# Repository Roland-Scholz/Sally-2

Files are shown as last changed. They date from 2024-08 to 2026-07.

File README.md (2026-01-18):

# Sally-2

An ATR8000 (https://www.atarimagazines.com/v3n4/ATR8000.php, http://atariki.krap.pl/index.php/ATR_8000) clone formerly made by SWP
and the Sally 1 by RSD (Rainer Storz Datentechnik)

Inspired by the repair of a Sally 1, which had been found in the attic, the
Atari-Bit-Byter-User-Club (www.abbuc.de) encouraged Marc and me to reproduce this lovely machine in a more compact way, 
though keeping a sort of retro-style.

We used 3 16V8 GALs in order to reduce chip count and replaced the WD1797 floppy-disc-controller by the more compact
WD1772 variant. Caveat: This chip is not designed for HD (500kbit/s) speed used by 3 1/2" and 8"-drives, although most 
can be overclocked to that speed. Only use WD1772PH-02-02 version and at your own risk.
If you can get hold on an AJAX chip used in e.g. ATARI STE, use this one as it is rated for HD and even ED speed (16/32 Mhz).

Build your own device: All required files, components and documentations can be found in the release drawer 
https://github.com/Roland-Scholz/Sally-2/tree/main/release

You also could become an ABBUC member and buy a DIY kit at https://www.abbuc.de
Join the illustrous community and take part in conventions and discussions.

After some testing and debugging, the vRetro VR177x FDC replacement can now be recommended for use with this interface.
See https://www.vretrodesign.com/products/vr177x-wd1770-wd172-vl1772-replacement

# FAQ
[click here for FAQ](faq.md)

# ToDo:
[click here for ToDo](todo.md)

# Key features:

- Operates either as standalone CP/M system or versatile ATARI 8-bit interface (up to 4 floppies, Centronics, RS232)
- Z80-CPU at 4Mhz
- 128k static RAM (64k usable)
- 8k EPROM, use any 8 / 16 / 32 / 64k device (burn sally2.hex at $8000)
- WD1772 FDC (or AJAX FDC or VR177x)
- Z80-CTC timer/counter 

Additionally we have added:

- 60.000 baud high speed SIO (Pokey divisor 8, drive responds to the "Get Speed Byte" command '?')
- Track buffer
- HD-support for 3 1/2" disks (ca. 1MB). (Format is same as 8", 2 sides, 77 tracks, 26 sectors/track, 256 bytes per sector)

# Final product ready as of October 2025

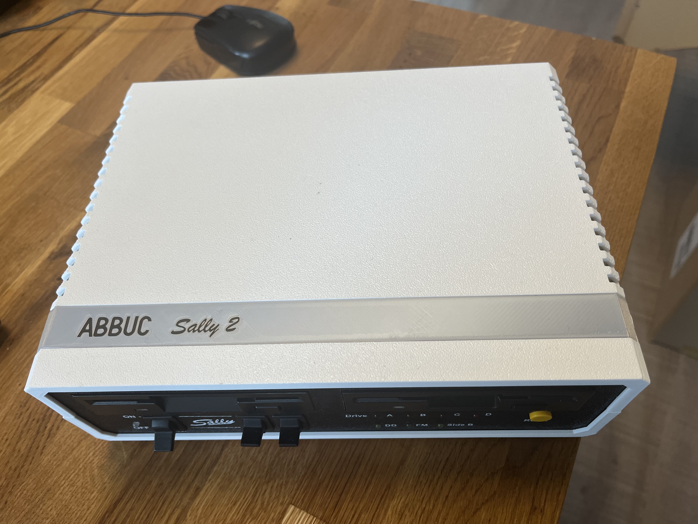
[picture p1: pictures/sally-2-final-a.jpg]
Sally-2-final-a

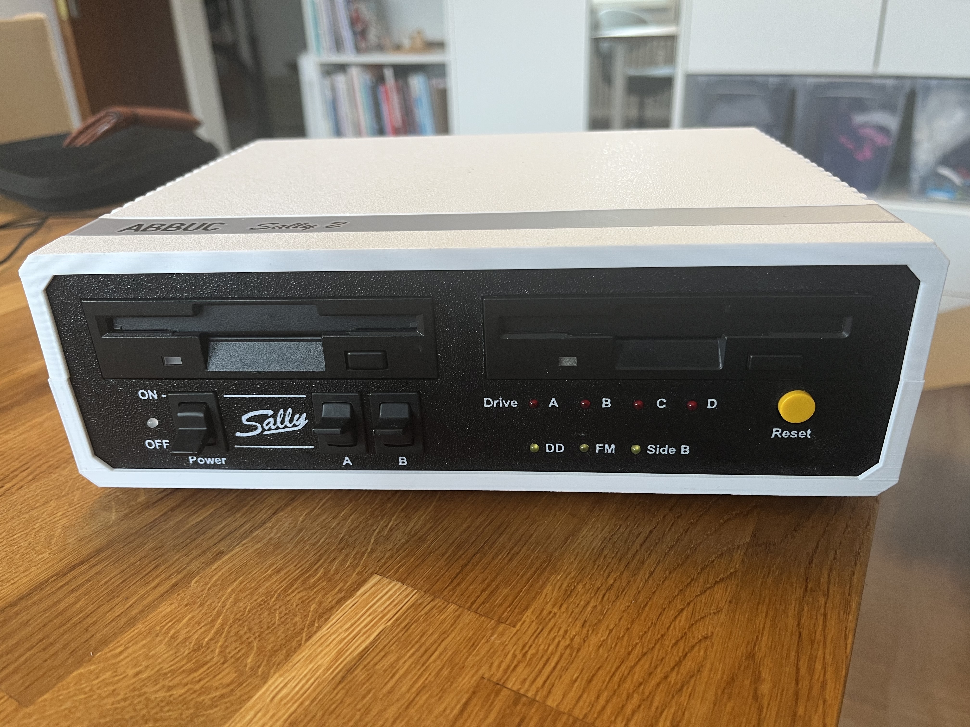
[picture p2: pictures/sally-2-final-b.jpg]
Sally-2-final-b


# further progress as of April 2025:

- Marc has completed a new manually routed PCB and 3 supporting PCBs for swicthes and connectors
- ATARI can read/write 3 1/2 HD disks formtted like 8"-disks (26sec x 77 trks x 2 sides = ca. 1MB)
  The challange was to allow for HD even for 300 rpm drives, instead of 360rom used by 8" and 5 1/4" drives.
- A full blown FAT-12 DOS for the ATARI is close to be finished, some more testing and minor additional features required/appreciated
- ABBUC now owns a Bumbu X1-carbon 3D printer, which has immediately been used to dress Sally-2 appropirately.

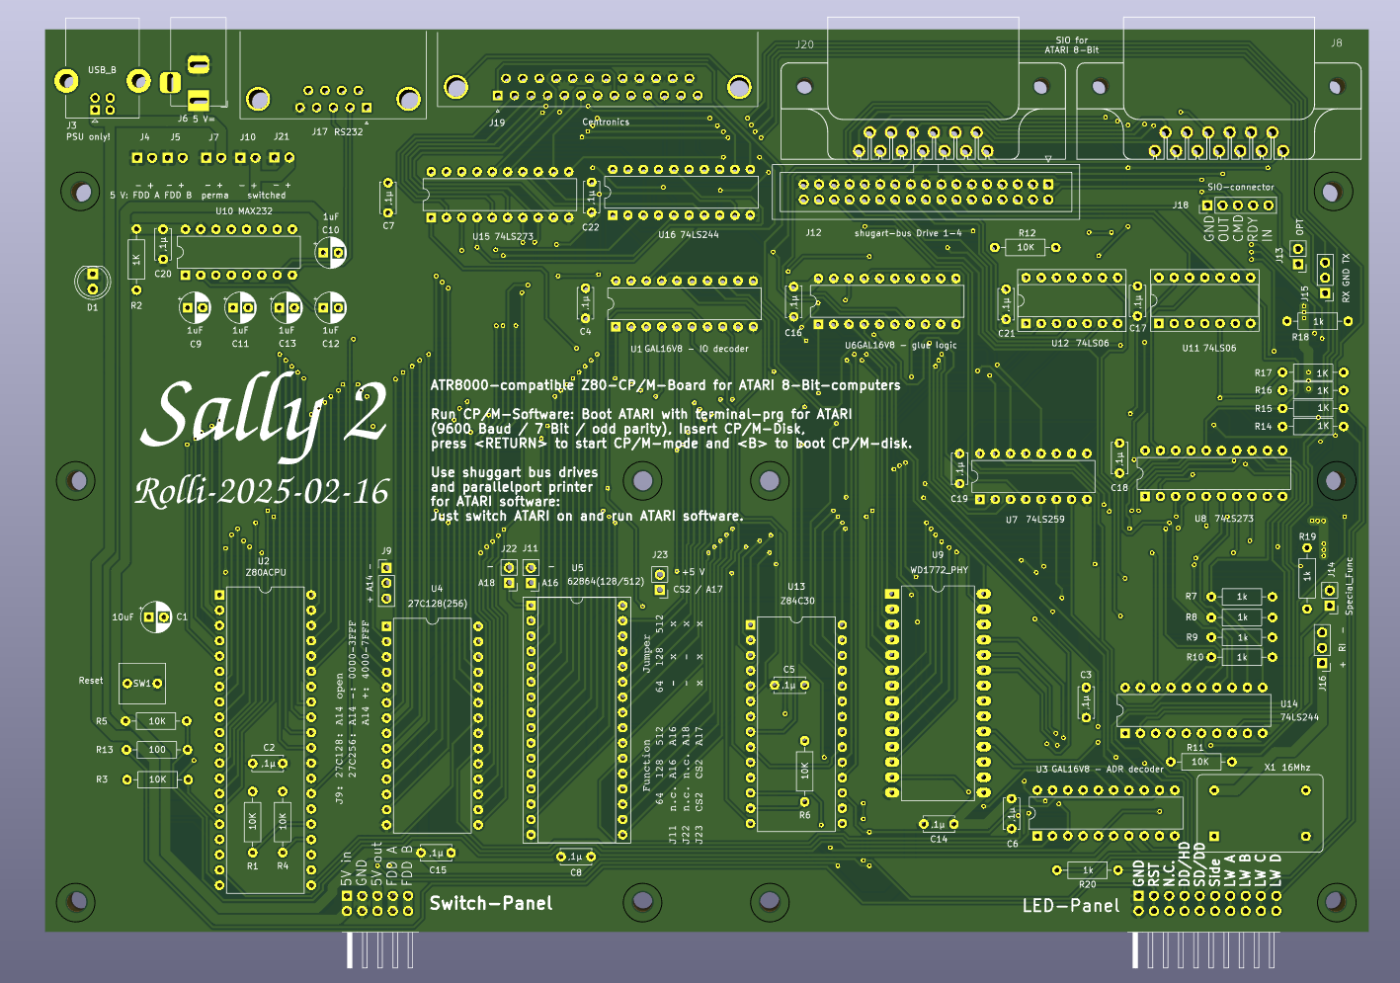
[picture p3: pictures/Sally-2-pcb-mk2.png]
Sally-2-pcb-mk2

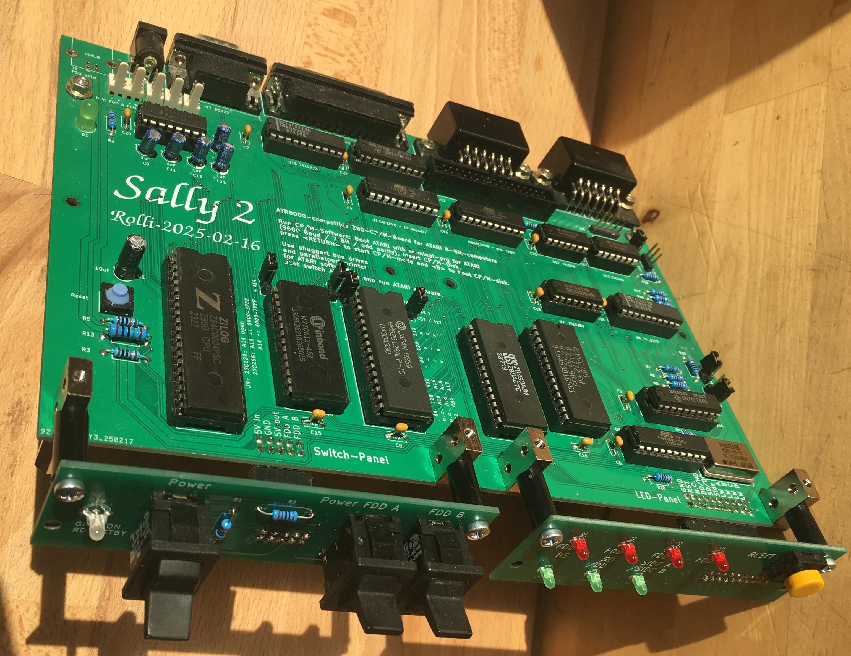
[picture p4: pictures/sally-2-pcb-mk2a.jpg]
Sally-2-pcb-mk2a

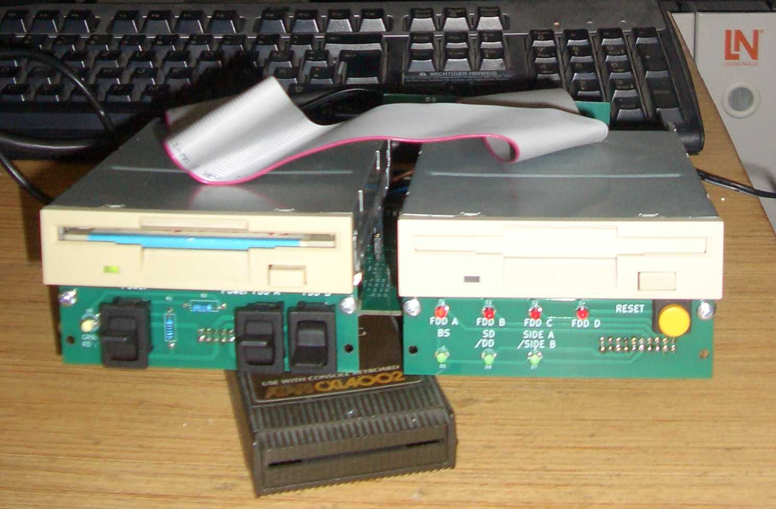
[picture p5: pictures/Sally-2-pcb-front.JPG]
Sally-2-pcb-front

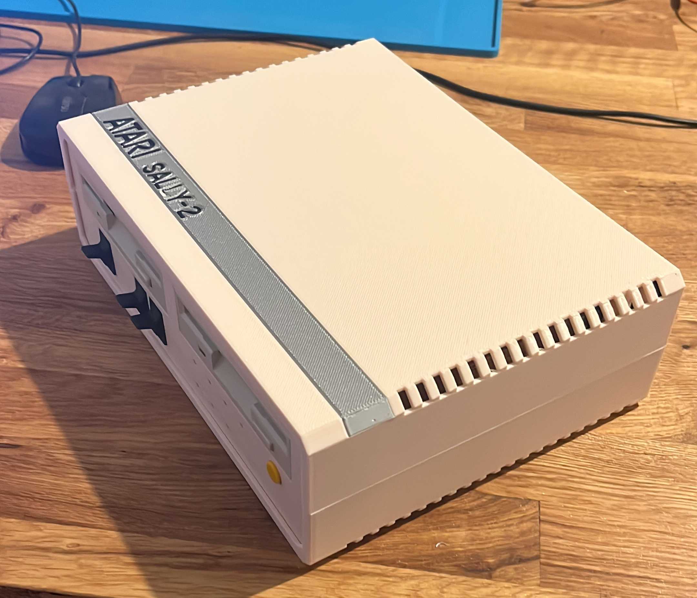
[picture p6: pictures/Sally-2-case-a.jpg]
Sally-2-case-a

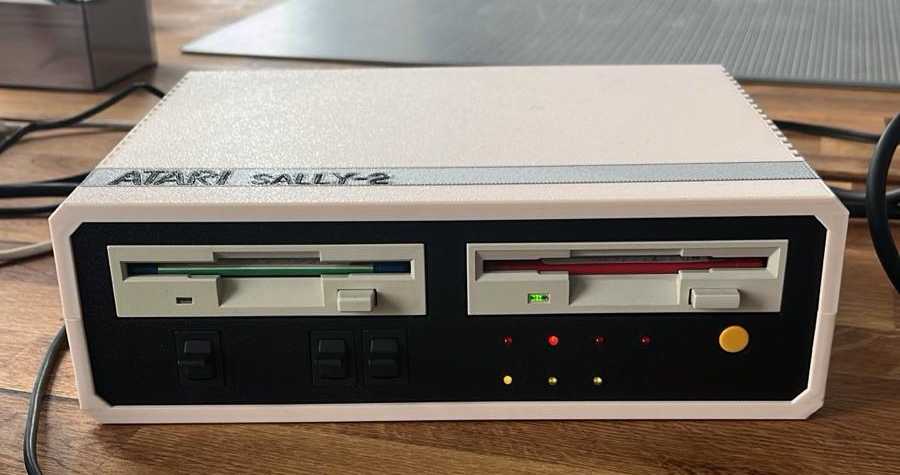
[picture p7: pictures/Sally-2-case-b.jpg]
Sally-2-case-b

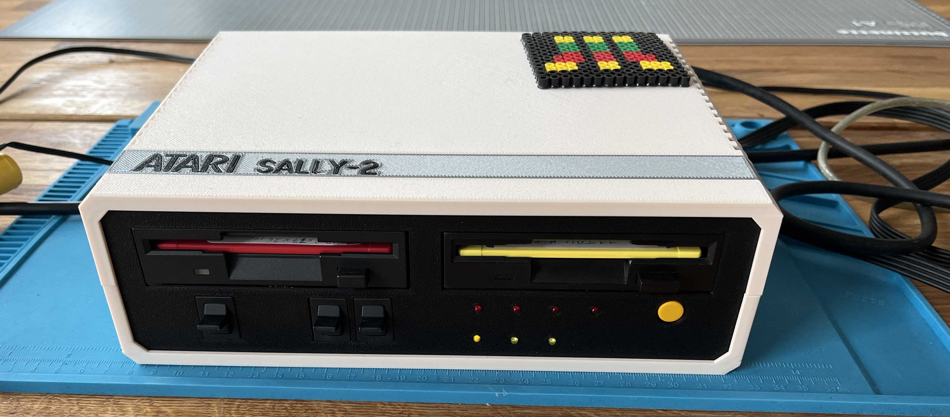
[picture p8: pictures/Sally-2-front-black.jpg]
Sally-2-case-front-black

First try, all-in-one print, label and case
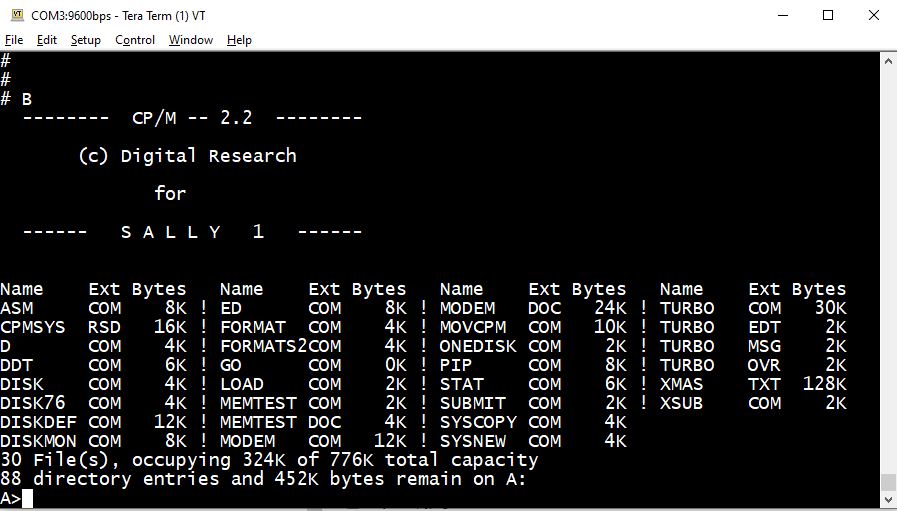
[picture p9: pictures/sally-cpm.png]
sally-cpm

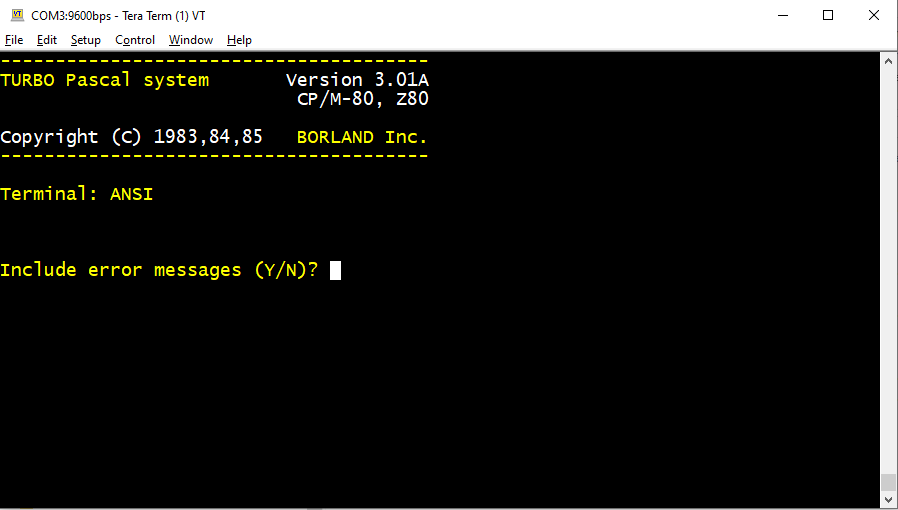
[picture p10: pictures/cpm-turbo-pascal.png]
cpm-turbo-pascal


# first attempts
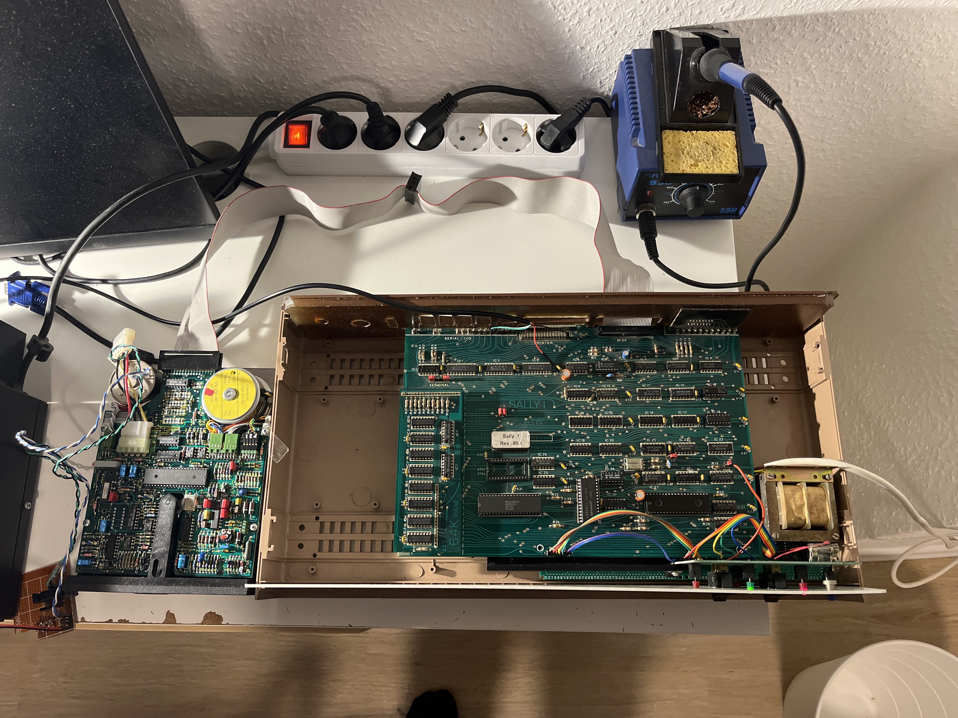
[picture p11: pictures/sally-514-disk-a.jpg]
Sally-514-disk-a

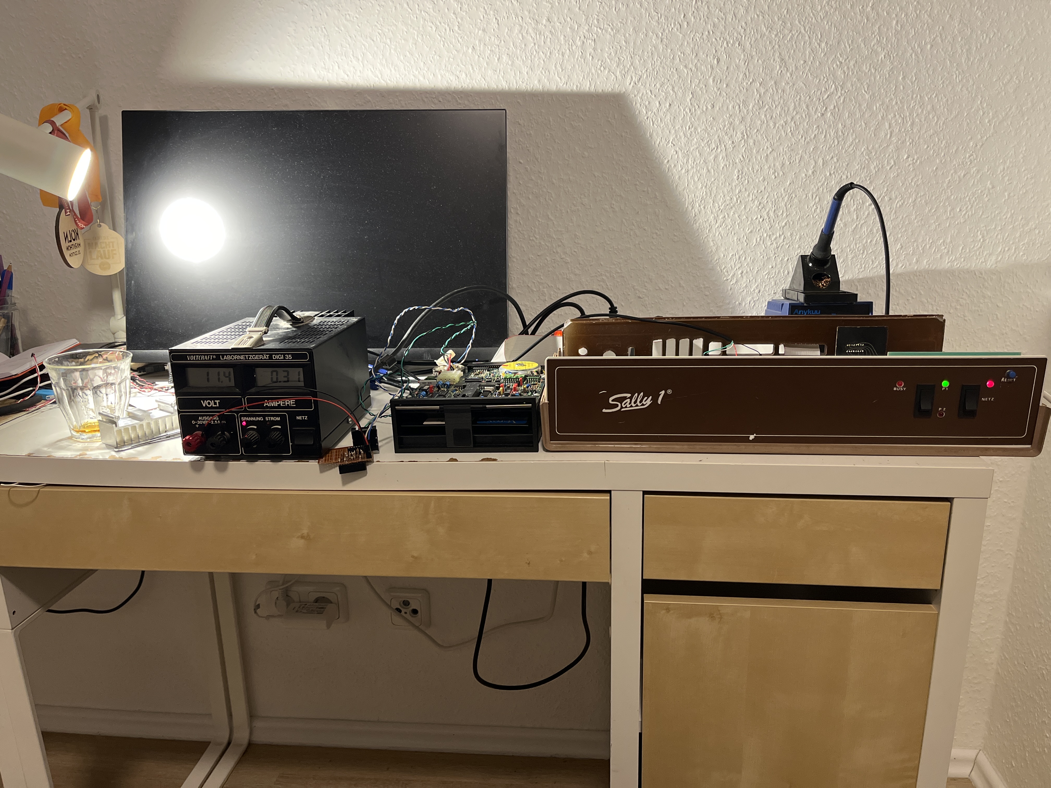
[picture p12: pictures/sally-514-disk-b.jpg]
Sally-514-disk-b

Original Sally 1 repaired (5 ICs were out of order) and tested with a 40Trk single sides drive.

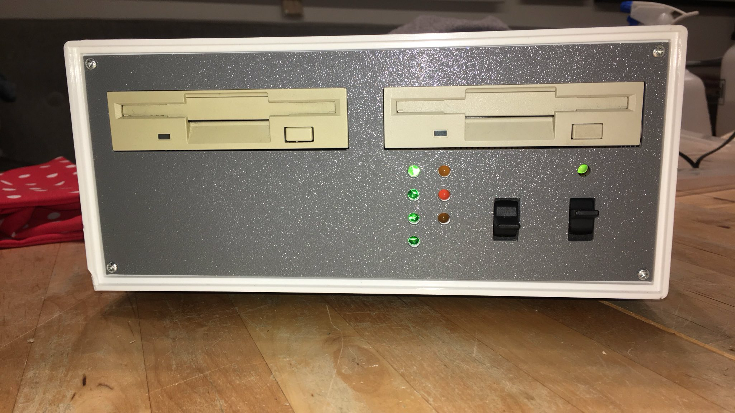
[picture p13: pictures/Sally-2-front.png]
Sally-2-front

Sally-2-back
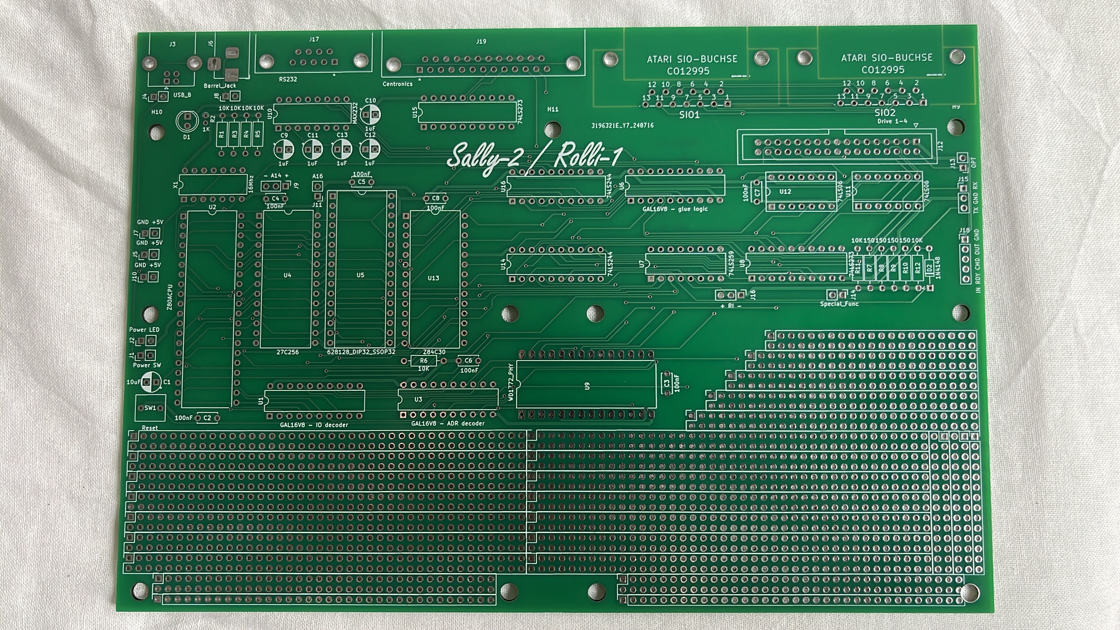
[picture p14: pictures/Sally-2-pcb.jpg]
Sally-2-pcb

First version of Sally 2 PCB and a case

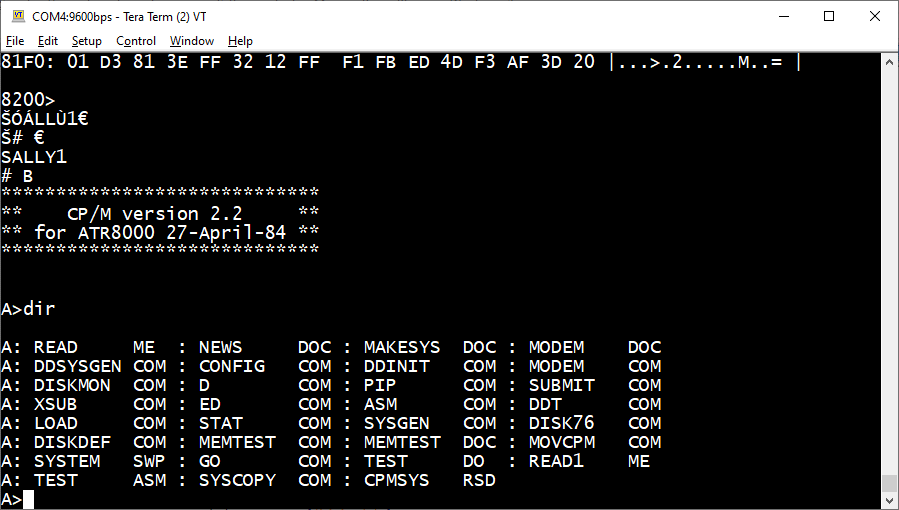
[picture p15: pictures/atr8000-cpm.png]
Atr8000-cpm

ATR8000 CP/M running on Sally 1 (todo: Add picture of the Sally CP/M version, which is apart from the messages identical to the ATR8000)

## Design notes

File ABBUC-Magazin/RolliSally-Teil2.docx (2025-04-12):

Rolli und Sally – Liebe auf den zweiten Chip

Teil II

Liebe Bit-Byter,

es ist schon wieder einige Zeit her, dass ich über die Reparatur der Sally, dem Fund aus Wolfgangs Keller, an dieser Stelle berichtet habe. Diesmal möchte ich ein wenig über die Fähigkeiten der Sally schreiben und was Marc (sleepπ) und ich (chaos) in der vergangenen Zeit so getrieben haben.

Also was ist die Sally eigentlich genau?

Versuchen wir einen Vergleich: Die Sally ist im Grunde ein von der Firma RSD (Rainer Storz Datentechnik, Duisburg) ausgeführter Nachbau des Interfaces ATR8000 der Firma SWP aus den USA. Hinzugefügt wurden nur kleinere Änderungen, die später noch beschrieben werden. Wir wissen zur Zeit nicht, ob das Gerät je in Serie Verkauft wurde, denn die zwei einzigen uns bekannten Stücke sind zwar funktionstüchtig, hätten aber wahrscheinlich aus sicherheitstechnischen Gründen nicht auf den deutschen Markt gebracht werden können bzw. dürfen.

Nun zur Frage, wenn die Sally im Prinzip ein ATR8000 ist, was kann bzw. ist denn dann ein ATR8000?

Die Hardware:

Prinzipiell besteht ein ATR8000 aus einer Z80-CPU, 64KB-RAM, 8-32KB ROM (abschaltbar), einem Z80-CTC (Timer/Counter) und einem WD 1797 Floppy-Disk-Controller, der so ziemlich alle Formate gängigen schreiben/lesen kann. Auch kann er mit 250kbit/sec oder mit 500kbit/sec arbeiten, sodass sowohl DD- als auch HD-Disketten verarbeitet werden können. Somit sind alle Diskettengrößen von 8-Zoll bis 3 ½ Zoll, Aufzeichnungsdichten und -formate (FM/MFM) einsetzbar. Lediglich das GCR-Verfahren, das Commodore und Apple verwendeten, kann nicht benutzt werden. Bis zu vier Diskettenlaufwerke können über den Shugart-Bus angeschlossen werden. Das sind die (früher) handelsüblichen Laufwerke, die es in vielen Variationen gibt. IBM hat für den PC den Shugart-Standard (leider) etwas verändert, aber mit einem passenden (u.U. selbst-konfektionierten) Kabel kann man auch PC-Laufwerke verwenden. Ohne viel Aufwand dann jedoch nur zwei, weil die Select-Leitungen der Shugart-Laufwerke 3 und 4 als Motor-ON Signale der PC- Laufwerke 1 und 2 verwendet worden sind.

Die Betriebsmodi:

Ein ATR8000 hat zwei Betriebsmodi: Einmal kann es als ATARI-Interface dienen und in dieser Betriebsart dem ATARI bis zu vier Diskettenlaufwerke, einen seriellen RS232 Port und eine Centronics-(Drucker)-Port zur Verfügung stellen. Zum anderen kann es sozusagen „stand-alone“ als Computer-System mit dem Betriebssystem CP/M betrieben werden. An dem SIO-Port des ATR8000 wird dann ein ADM-3A Terminal benötigt. Es gibt dazu sogar zwei passende Terminal-Emulationen für den ATARI, eine, die im 40-Zeichen Modus arbeitet und eine, die einen in Software emulierten 80-Zeichen-Modus bietet. Ein CP/M 2.2-Betriebssystem mit einigen Werkzeugen liegt dem System bei.

ATARI-Modus:

Im ATARI-Interface Modus werden bei DD-Disketten immer 18 Sektoren pro Track geschrieben. Das bedeutet aber auch, dass das sogenannte Enhanced-Density mit 26 Sektoren, nicht verarbeitet werden kann. Durch die Konfiguration des PERCOM-Blocks muss der Nutzer festlegen, welches Aufzeichnungsformat verwendet werden soll, also wie viele Tracks pro Seite und wie viele Seiten die Diskette haben soll. Das Aufzeichnungsformat kann entweder FM bzw. single-density oder MFM bzw. double-density sein. Da die meisten Diskettenlaufwerke 80 Tracks unterstützen, ist ein typisches Format, das mit 250kbit/sec geschrieben wird, wäre z.B.:

256 Bytes * 18 Sektoren * 80 Tracks * 2 Seiten = 720KB

Der Floppy-Disk-Controller aber auch mit 500kbit/sec, also mit HD (high-density) lesen und schreiben. 8-Zoll Laufwerke und die vom PC bekannten HD-Laufwerke können diese Dichte verwenden. Die 8-Zoll-Laufwerke sind mit 77 Tracks spezifiziert, daher formatiert ein ATR8000 dann eine Diskette mit

256 Bytes * 26 Sektoren * 77 Tracks * 2 Seiten = 1001KB

Wieder über den PERCOM-Block kann man diese Werte einstellen, insbesondere wird an der Eingabe von 77 Tracks erkannt, dass die Schreibdichte doppelt so hoch sein soll. Auf einer modernen 3 ½ Zoll Diskette (früher waren sie modern im Vergleich zu 8-Zoll Laufwerken) könnte man noch drei Tracks und wegen der geringeren Drehzahl von 300upm gegenüber den 360upm eines 8-Zoll Laufwerks auch mehr Sektoren pro Track unterbringen. Die Anpassung der Firmware und die Unterscheidung der Formate wären aber recht kompliziert. Eine gängige HD-Diskette speichert ja 1440KB, das wären schon noch ein paar KB mehr.

Weiterhin bietet das ATR8000 auch eine RS232 Schnittstelle, die bis 19200 betrieben werden kann. Im praktischen Betrieb unter CP/M mit einer XMODEM Terminal-Software konnte ich es nur bis 9600 Baud stabil verwenden. Auch im ATARI-Modus mit einem Treiber für Bobterm oder ICE-Term war ein XMODEM-Transfer nur bis 9600 Baud stabil.Auch wenn die Hardware eingeschränkt auch Datenfluss-Kontrollsignale bereitstellt (RTS/CT bzw. DSR/DTR), so wurden diese, soweit ich das erkennen konnte, von keinem Treiber verwendet.

Die Centronics-Schnittstelle funktioniert gut und das interne RAM wird als Druckerpuffer verwendet. Besondere Auffälligkeiten konnten Marc und ich bisher nicht feststellen.

CP/M-Modus:

CP/M war eines der ersten Betriebssysteme für Kleincomputer, das sämtliche Ein-/Ausgaben über einen Satz von einfachen BIOS-Routinen ausführt. Somit müssen für ein neues Computersystem nur diese BIOS-Routinen angepasst werden und schon läuft ein CP/M. Ein Nachteil war allerdings dass das BIOS nur zeichenbasiert arbeitet und im Grunde immer für eine Art Terminal vorgesehen war und damit spezifische Fähigkeiten hinsichtlich Grafik oder Sound nicht standardisiert verwendet werden konnte. Das sieht man z.B. daran, dass das bekannte Turbo-Pascal von Borland bestimmt 40 Treiber für verschiedenen Systeme mitlieferte. Aber wie gehabt, die Ein-Ausgabe auf Geräte wie Terminal, Drucker und Diskettenlaufwerke sind abstrahiert und schnell an neue Rechner anpassbar.

Der ATR8000 wie die Sally bringen ein jeweils ein (identisches) CP/M 2.2 mit, dessen BIOS dann auf die Hardware des ATR8000 zugreift. Für die Sally wurden die Meldungstexte eingedeutscht, die Funktion und Umfang der Tools hat sich nicht geändert.

Es gibt Programme zur Formatierung von Disketten, ein Terminal-Programm und weitere Tools um bestimmte Diskettenformate zu setzten. Auch kann man sein CP/M-System klonen oder neu konfigurieren. Denn die Geometrie der angeschlossenen Laufwerke müssen dem CP/M in bestimmten Kontrollblöcken in den Boot-Sektoren mitgeteilt werden. Das CP/M wird auf die ersten (dafür reservierten) Tracks einer Diskette geschrieben und bei einem Neustart von diesen Tracks eingelesen.

Die serielle Kommunikation mit dem Terminal muss auf 9600 Baud, 7 Bit und odd Parity eingestellt werden und als Terminal-Steuerzeichen wird das Befehlssatz der ADM-3A Terminals verwendet. Ein recht einfaches Terminal, das auch nur Großbuchstaben verwendet.

Im Bild ist dargestellt, wie gerade Borland Turbo Pascal 3.02 gestartet ist und über ein VT100-Terminal bedient wird. Im Grunde sollte auch jede anderen CP/M-Software mit dem System laufen.

Sally:

Die Sally-Firmware ist bis auf die Texte Byte für Byte identisch mit der ATR8000-Firmware, wir haben die ROMs verglichen. Dennoch gibt es folgende Änderungen an der Hardware:

Sie hat eine Busy-Lampe, die immer dann leuchtet, wenn entweder auf ein Diskettenlaufwerk oder auf die serielle Schnittstelle zugegriffen wird.

Sie hat 4 SIO-Ports, man kann also mehrere ATARIs an die Sally anschließen. Jedoch muss man ohne den Prioritätsencoder (s.u.) dringend darauf achten, dass immer nur ein ATARI auf der SIO-Leitung aktiv ist. Aus meiner Sicht ein recht fragwürdiges Feature.

Weiterhin gibt es eine kleine Erweiterung, die den SIO-Ports Prioritätsencoder hinzufügt. Wenn als gerade ein ATARI Daten austauscht, sind die anderen ATARI von der Kommunikation hardwaremäßig abgetrennt. Das verhindert ein wenig Datensalat auf der SIO-Leitung, ergibt aber m.E. immer noch kein vollwertiges/verlässliches Multi-Computer Netzwerk.

Sally-2:

Carsten (Cas) hatte angeregt, ob Marc und ich nicht einen leicht modernisierten Nachbau der Sally konstruieren und der Allgemeinheit zugänglich machen könnten. Unsre Ehrgeiz war schnell geweckt und schon im Juni 2024 hatten wir die erste Platine auf dem Schreibtisch liegen. Nachzulesen ist das alles en detail im Basecamp der AReWe. Aber hier zuerst einmal die Grundgedanken:

- Irgendwie sollte es ein wenig Retro sein, da ja Disketten selbst mit dem Atari kaum noch verwendet werden und fast jeder ein SD-Leser oder ein Fujinet am Start hat. Man könnte auch alles in einem Microcontroller emulieren, aber das ist nicht unser Geist.
- Funktionsumfang gleich dem des ATR8000, da die Sally-Erweiterungen marginal bis nutzlos sind.
- Floppy-Controller: Umstieg auf den WD1772-PH-02-02, denn der WD1797 ist wirklich gar nicht mehr zu bekommen und die PLL-Schaltung funktioniert extern mit einem PROM, das mit 25V programmiert werden muss und auch so gut wie nicht mehr erhältlich ist. Der WD1772 hat den PLL mit eingebaut. Da er im ATARI ST, XF551 und andere Floppys eingebaut war, bekommt man ihn hier und da noch. Allerdings ist er eigentlich nur für DD (also 250kbit/sec) und nicht für HD spezifiziert. Jedoch lassen sich die meisten Chips der Version WD1772-PH-02-02 ohne Probleme übertakten und kommen auch mit HD (500kbit/sec) zurecht. Wem das zu kriminell ist, der nutzt eben nur SD/DD Disketten.
- Vereinfachung und Zusammenfassung der vielen 74LSxx-Logik-Bausteine in drei GAL16V8
- Dynamisches RAM wird durch statisches RAM ersetzt.
- Erweiterung der Firmware um:
  - 60.000 baud high speed SIO (Pokey divisor 8)
  - Track-Buffer
  - HD-Support für 3 1/2" disks (ca. 1MB). (Format wie für 8", 2 Seiten, 77 Tracks, 26 Sektoren/Track, 256 Bytes pro Sektor)
  - MS-DOS (FAT12) Format lesen/schreiben per neuem ATARI-DOS

Wie bei jedem Prototyp waren natürlich (kleine) Flüchtigkeitsfehler auf der Platine und leider auch ein Größerer, weil nämlich der Daten- und Adressbus zwischen CPU- und IO-Bereich durch eine Besonderheit von KiCad nicht verbunden waren. Auch hatte ich einen IO-Baustein falsch angeschlossen, weil ich den originalen Schaltplan nicht genau genug beachtet hatte. Aber nach ein wenig Schwingen des Lötkolbens hatten Marc und ich schnell die ersten Funktionstüchtigen Prototypen (Roland: Rolli, Marc: Molli) arbeitsbereit.

Das Umprogrammieren auf den nicht vollständig kompatiblen Floppy-Controller und Erweitern der Firmware war viel interessante Detektivarbeit und hat manchmal etwas Frust aber meistens viel Spaß gebracht. Die Sally-2 ist nun deutlich schneller als das Original und kann mit HD-Disketten im 3 ½-Format umgehen.

Aktuell schreibe ich noch an dem FAT12-DOS (90% fertig), würde mich aber freuen, wenn wir da Unterstützung bekommen könnten.

Nachdem ja jetzt die Prototyp-Platine funktionierte, hat Marc sich die Mühe gemacht und die Platine noch einmal von Hand komplett neu geroutet und alle Beschriftungen perfektioniert. Außerdem fanden wir das Metall-Gehäuse (ein blaues Standard-Teil aus China) nicht so passend zu unserem Atari, sodass Marc noch kleine Platinen für die Frontbedienung entwickelte und damit das Design in der Höhe deutlich reduzieren konnte. Jetzt warten wir auf einen neuen 3D-Drucker, den der ABBUC uns und allen Mitgliedern zur Verfügung stellt. Wenn er angekommen ist, werden wir versuchen uns in die Kunst des 3D-Drucks einzuarbeiten, mit dem Ziel ein ATARI-ähnliches Gehäuse (evtl. zwei Versionen, XL weiß-schwarz oder XE grau) für die Sally-2 zu erstellen. Anschließend planen wir die Sally-2 als Bausatz den ABBUC-Mitgliedern zum Selbstkostenpreis bestellbar zu machen.

Das war es erst einmal von meiner Seite. Ihr findet hier noch viele Links, falls Ihr Euch noch weiter in bestimmte Themen einlesen wollt. Fragen und Mitarbeit sind jederzeit sehr willkommen und wir halten Euch auf dem Laufenden wie es mit der Liebe auf den zweiten Chip weitergeht.

Euer Roland (chaos)

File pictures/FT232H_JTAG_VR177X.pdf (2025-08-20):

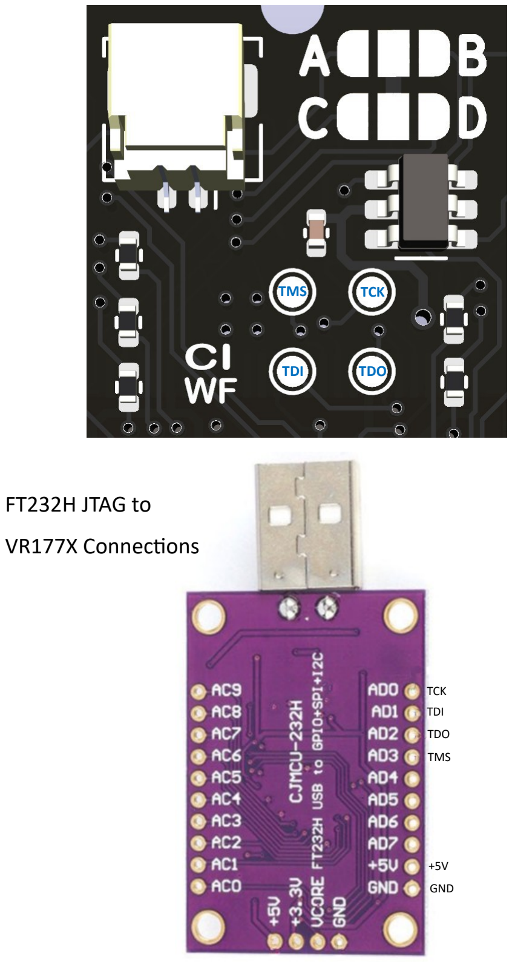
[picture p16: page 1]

TMS | TCK
TDI | TDO

TCK
TDI

TDO

TMS

+5V
GND

FT232H JTAG to

VR177X Connections

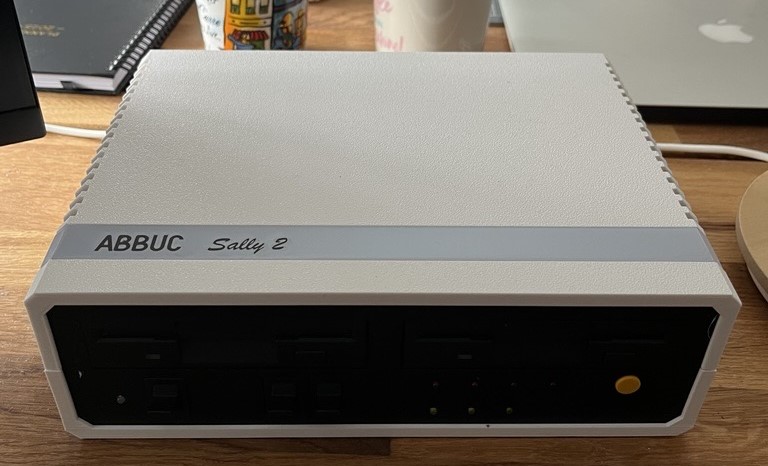
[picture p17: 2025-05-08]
pictures/sally-2-abbuc-a.jpg

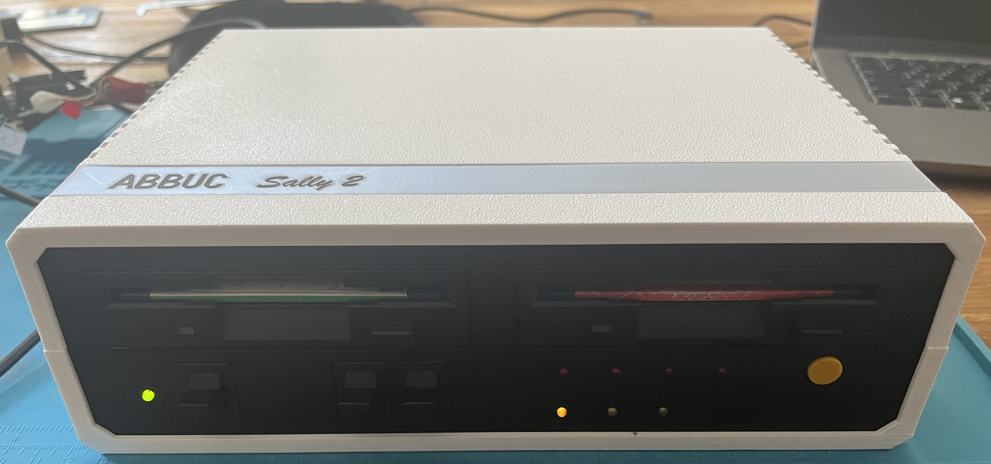
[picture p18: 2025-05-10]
pictures/Sally-2-front-black-a.jpeg

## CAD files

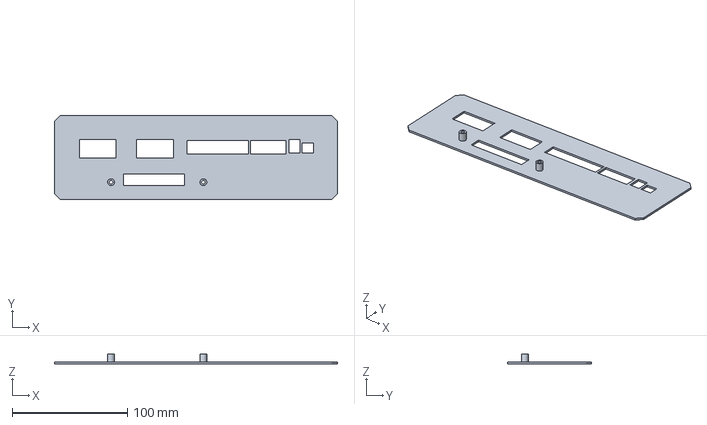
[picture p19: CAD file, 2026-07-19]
case/sally-2-back-text.3mf
245.2 x 73.2 x 8.60 mm

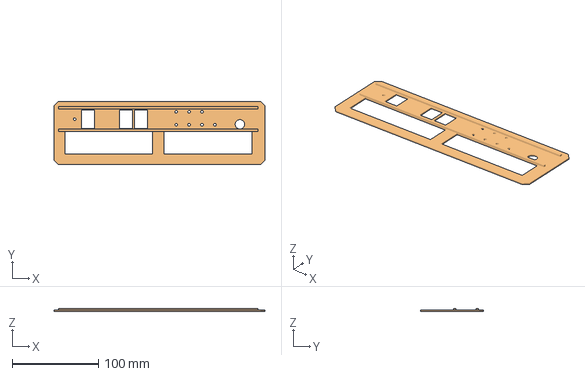
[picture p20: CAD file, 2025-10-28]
case/sally-2-front.3mf
245.2 x 73.2 x 3.60 mm
sally-2-front-text-logo.stl
sally-2-front.stl

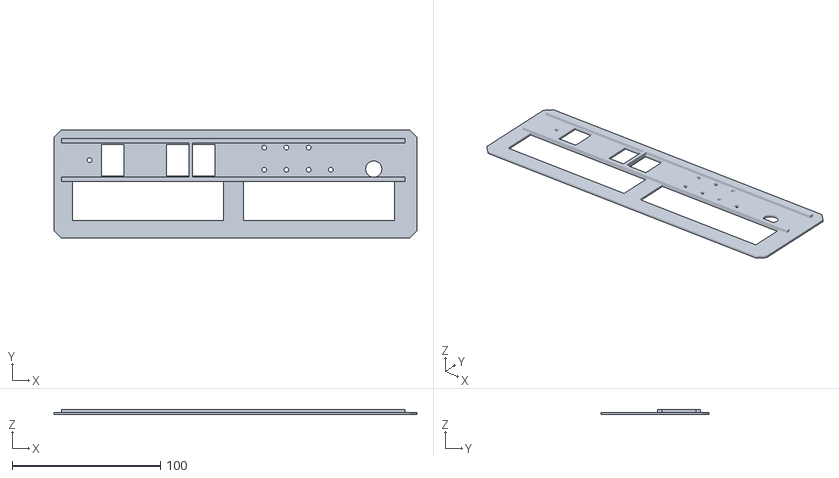
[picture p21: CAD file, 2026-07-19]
release/case/sally-2-front.stl
245.2 x 73.2 x 3.60

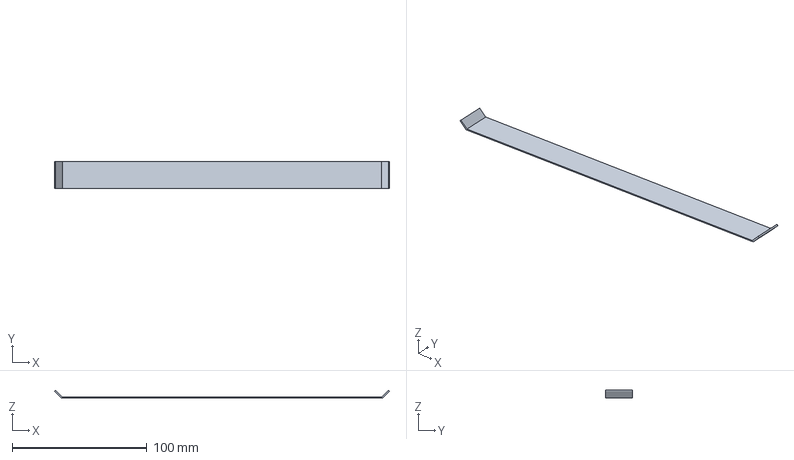
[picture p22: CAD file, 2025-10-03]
case/sally-2-top-1.3mf
249.0 x 20.0 x 5.80 mm

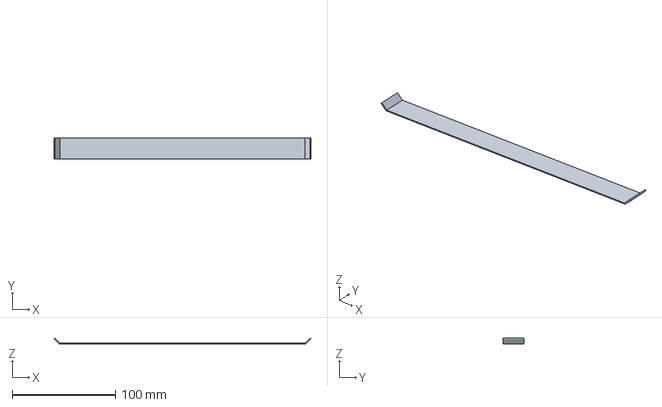
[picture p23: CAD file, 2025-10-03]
release/case/sally-2-top-2.3mf
249.0 x 20.0 x 5.80 mm

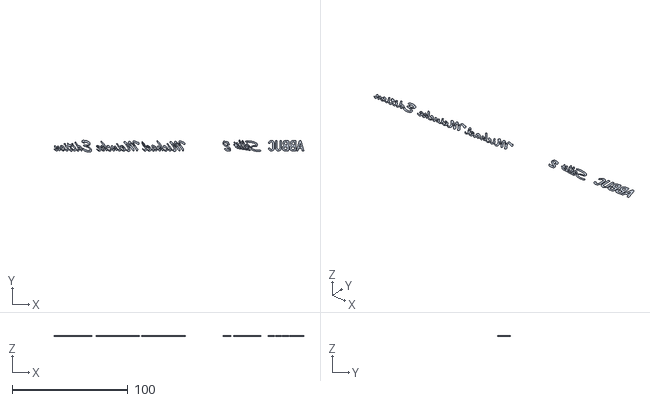
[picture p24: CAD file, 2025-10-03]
case/sally-2-top-2.stl
216.3 x 10.8 x 0.2

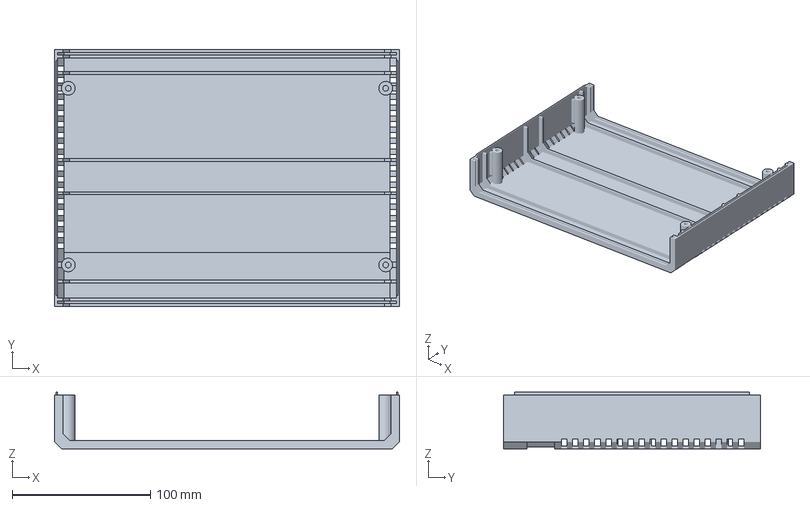
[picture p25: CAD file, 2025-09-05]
release/case/sally-2-top.3mf
250.0 x 186.0 x 41.0 mm

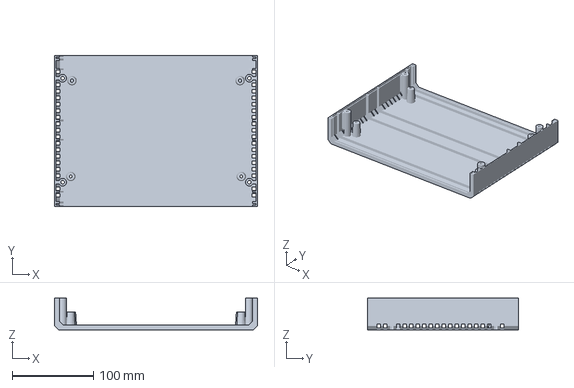
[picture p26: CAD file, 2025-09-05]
release/case/sally-2-bottom.3mf
250.0 x 186.0 x 39.0 mm

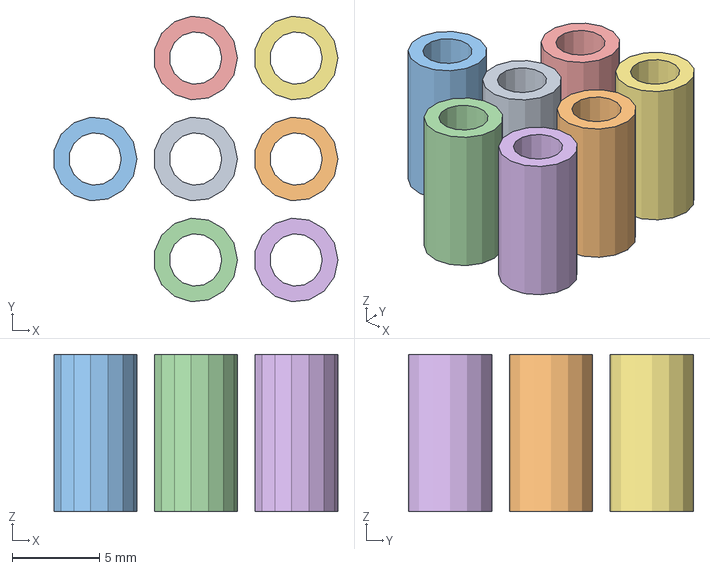
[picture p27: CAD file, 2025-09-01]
case/spacer-led.3mf
16.2 x 16.3 x 9.00 mm
spacer-led.stl x 7

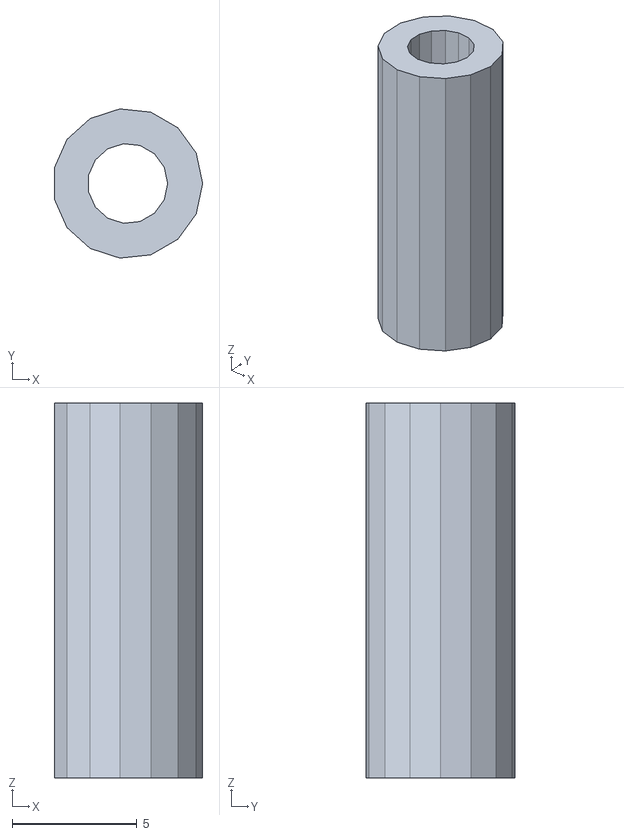
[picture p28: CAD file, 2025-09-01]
release/case/spacer-round-15.stl
5.93 x 5.97 x 15.0

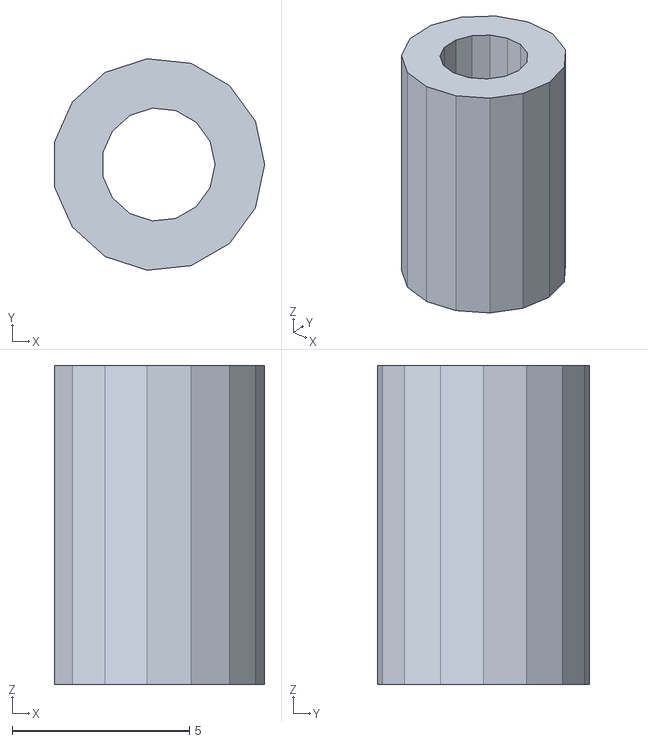
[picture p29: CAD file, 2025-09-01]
case/spacer-round-9.stl
5.93 x 5.97 x 9.00

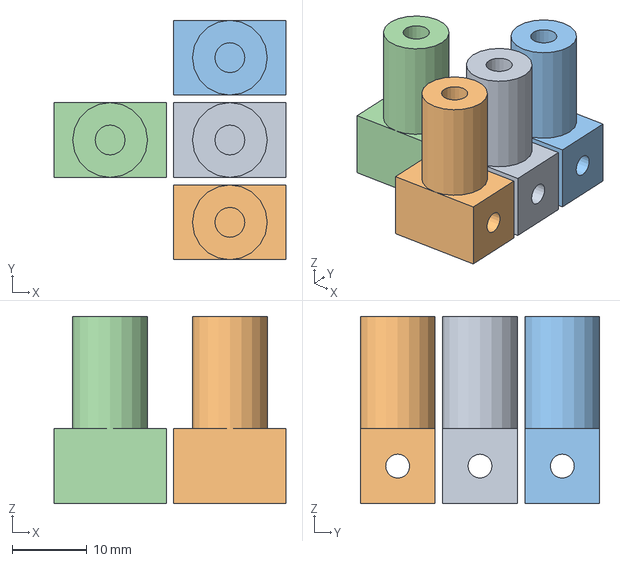
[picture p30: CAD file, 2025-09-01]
case/spacer.3mf
31.0 x 32.0 x 25.0 mm
spacer.stl x 4

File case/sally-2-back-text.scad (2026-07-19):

beschriftung();

module beschriftung() {
    
    translate([60, -46, 0])
    linear_extrude(0.4){
        rotate([180, 0, 0])
            text("1                SHUGART", 3, "Arial:style=Bold");
    }

    translate([33, -16, 0])
    linear_extrude(0.4){
        rotate([180, 0, 0])
            text("SIO                                      SIO                                 CENTRONICS                       RS232          Vin    FUNC", 3, "Arial:style=Bold");
    }

}

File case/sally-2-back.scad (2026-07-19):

$fn = 20;

thick = 2;
tf = 1.2;

xmax = 250;
ymax = 180+thick;
zmax = 39*2;

dev_x = 21.5;
dev_bot = 21;

edge=5;

translate([0, 0, 1.6])
    rotate([180,0,0])
        shape();

module shape() {
    difference(){
        base_shape();
        
        translate([dev_x, dev_bot, 0])
            sio();
        
        translate([dev_x+17.5+32, dev_bot, 0])
            sio();
        
        translate([dev_x+17.5+31+32+13, dev_bot+1, 0])
            par();
        
        translate([dev_x+17.5+31+32+13+53+2, dev_bot+1, 0])
            ser();

        translate([dev_x+17.5+32+32+12+86+2, dev_bot, 0])
            barrel();
        
        translate([dev_x+17+32+32+12+86+3+9+2, dev_bot, 0])
            dipswitch();

        translate([60+60.5, 63,0])
            floppy();
        
    }
    
    /*
    translate([0,0,1]) 
        rotate([180, 0, 0]) 
            beschriftung();
    */
    
    /*
    translate([edge, zmax-4*thick-edge, -thick])
        cube([xmax-2*edge-4*thick, 3, 3]);

    translate([edge, 32, -thick])
        cube([xmax-2*edge-4*thick, 3, 3]);

    translate([edge, 5, -thick])
        cube([xmax-2*edge-4*thick, 3, 3]);
    */

}

module dipswitch() {
    cube([10, 11.5, thick]);
}

module barrel() {
    cube([9.5, 11.5, thick]);
}

module par() {
    cube([53, 11.5, thick]);
}

module ser() {
    cube([30.5, 11.5, thick]);
}

module sio() {
    cube([32, 16, thick]);
}

module base_shape() {
    
    rotate([0,0,0])
    linear_extrude(1.6)
        base_shape_2d(thick * tf);
    
    translate([60+60.5+8.5, 58, -7])
        spacer_round();
    translate([49, 58, -7])
        spacer_round();

}

module base_shape_2d(th) {
    
    echo("width:", xmax-2*th);
    echo("height:", zmax-2*th);
    
    polygon([[0, zmax-edge-2*th], [0, edge], [edge,0], [xmax-edge-2*th, 0], [xmax-2*th, edge], [xmax-2*th, zmax-edge-2*th],[xmax-edge-2*th, zmax-2*th], [edge, zmax-2*th]  ]);
}

module floppy() {
    rotate([0,0,180])
    translate([0,0,-thick]) {
        translate([8, 2, 0])
    cube([52.5, 10, 2*thick]);
    
    translate([60+11.5, 5, 0])
        cylinder(2*thick, 2, 2);
    
    translate([-8.5, 5, 0])
        cylinder(2*thick, 2, 2);
    }
}

module spacer_round() {
    difference(){
        cylinder(h=7, r=3);
            cylinder(h=7, r=1.6);
        
    };
}

module beschriftung() {
    
    translate([60, -47, -1.6])
    linear_extrude(1.0){
        rotate([180, 0, 0])
            text("1                SHUGART", 3, "Arial:style=Bold");
    }

     translate([33, -16, -1.6])
    linear_extrude(0.2){
        rotate([180, 0, 0])
            text("SIO                                      SIO                                 CENTRONICS                       RS232          +5V  FUNC", 3, "Arial:style=Bold");
    }

}

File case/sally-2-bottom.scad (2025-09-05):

$fn = 20;

thick = 2;
xmax = 250;
ymax = 180+thick;
zmax = 39;

edge=5;

//xmt = xmax + 2*thick;
//ymt = ymax + 2*thick;    

//   shell_bot();

difference() {
    shell_bottom();

    //holes for screws pcb
    
    translate([20, 35,0])
        cylinder(4, 3.5, 3.5);
    translate([xmax-20,35,0])
        cylinder(4, 3.5, 3.5);
    /*
    translate([21.5,35+118,0])
        cylinder(4, 3.5, 3.5);
    translate([xmax-21.5,35+118,0])
        cylinder(4, 3.5, 3.5);
    */
    
    //bumper (rubber feet)
    
    translate([35, 27.5, 0])
        cylinder(1, 1, 1);
    translate([xmax-35, 27.5,0])
        cylinder(1, 1, 1);
    translate([35, ymax-27.5, 0])
        cylinder(1, 1, 1);
    translate([xmax-35, ymax-27.5, 0])
        cylinder(1, 1, 1);
 
}


module shell_bottom() {
    
    difference(){
        base_shape();
        cubes_left();    
        cubes_right();
        
        //holes for screws case
        translate([edge+5,28,0])
            cylinder(4, 3.5, 3.5);
        translate([xmax-edge-5,28,0])
            cylinder(4, 3.5, 3.5);
        translate([edge+5,ymax-26,0])
            cylinder(4, 3.5, 3.5);
        translate([xmax-edge-5,ymax-26,0])
            cylinder(4, 3.5, 3.5);

        //clips left right
        translate([thick/2,3*thick,zmax-thick-1])
            cube([thick/2,ymax-6*thick, 3]);
        translate([xmax-thick,3*thick,zmax-thick-1])
            cube([thick/2,ymax-6*thick, 3]);


    }


    translate([0, ymax+thick])
        base_shape_holder();
    translate([0, ymax-thick])
        base_shape_holder();
    translate([0, 0])
        base_shape_holder();
    translate([0, 0+2*thick])
        base_shape_holder();    


    
    translate([0, 26, 10])
        cube([8,4,25]);
    translate([0, ymax-28, 10])
        cube([8,4,25]);
    translate([xmax-edge-2*thick+1, 26, 10])
        cube([8,4,25]);
    translate([xmax-edge-2*thick+1, ymax-28, 10])
        cube([8,4,25]);
    
    //feet, set PCB on top
    translate([20,35,0])
        foot_small(3, 22);
    translate([xmax-20,35,0])
        foot_small(3, 22);
        
    translate([21.5,35+118,0])
        foot_big(3, 22);
    translate([xmax-21.5,35+118,0])
        foot_big(3, 22);
}



module base_shape() {
    translate([0, ymax+thick, 0])
        rotate([90,0,0]) 
            linear_extrude(ymax+thick)
                base_shape_2d(thick);

    //screws holding case together
    translate([edge+5,28,0])
        screw(4);
    translate([xmax-edge-5,28,0])
        screw(4);
    translate([edge+5,ymax-26,0])
        screw(4);
    translate([xmax-edge-5,ymax-26,0])
        screw(4);
    
    //reinforcement front
    translate([0, 17 ,0])
        base_shape_holder();    
    
    //reinforcement in the middle
    translate([0, ymax/2 - 10])
        base_shape_holder();    
    translate([0, ymax/2 + 14])
        base_shape_holder();    

    //reinforcement back
    translate([0, ymax-14 ,0])
        base_shape_holder();    

}

module base_shape_holder() {
    
    rotate([90,0,0])
    linear_extrude(thick)
        base_shape_2d(3*thick);

}

module base_shape_2d(th) {
    polygon([[0, zmax], [0, edge], [edge,0], [xmax-edge, 0], [xmax, edge], [xmax, zmax],[xmax-th,zmax], [xmax-th, edge+th], [xmax-edge-th, th],[edge+th, th], [th, edge+th],[th, zmax]]);
}

module cubes_left() {
    for(i = [10:8:ymax-14])
      translate([0, i, 0])
      cube([edge+thick, 4, edge+thick]);
}

module cubes_right() {
    for(i = [10:8:ymax-14])
      translate([xmax-edge-thick, i, 0])
      cube([edge+thick, 4, edge+thick]);
}
    
module screw(r) {    
    difference() {
        cylinder(zmax,r*1.2,r*1.2);
        translate([0,0,-1]);
            cylinder(zmax+2,r/2+0.2,r/2+0.2);
//        cylinder(5,6,6);
    }
}

module foot_big(r, h) {    
    difference() {
        cylinder(h,r*2,r*1.5);
            cylinder(h, 2.1, 2.1);
//        cylinder(5,6,6);
    }
}

module foot_small(r, h) {    
    difference() {
        cylinder(h,r*2,r*1.5);
            cylinder(h, r/2+0.2,r/2+0.2);
//        cylinder(5,6,6);
    }
}

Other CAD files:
release/case/sally-2-back.stl
case/sally-2-back.stl
case/sally-2-front-text-logo.3mf
release/case/sally-2-front-text-logo.3mf
case/sally-2-front-text.3mf
case/sally-2-front-text-logo.scad
KiCad/atari-sio-connector-master/gerber/SIOSocket-B_SilkS.dxf
KiCad/atari-sio-connector-master/gerber/SIOSocket-F_SilkS.dxf
case/sally-2-back-text.stl
case/sally-2-front-text.scad
case/sally-2-front-text.stl
case/sally-2-front.scad
case/sally-2-top-1.scad
case/sally-2-top-1a.scad
case/sally-2-top-1a.stl
case/sally-2-top-2.scad
case/sally-2-top.scad
case/spacer-led.scad
case/spacer-round-15.scad
case/spacer-round-9.scad
case/spacer.scad
case/washer.scad
release/case/sally-2-back-text.stl
release/case/sally-2-bottom.stl
release/case/sally-2-front-text-logo.stl
release/case/sally-2-top-1.stl
release/case/sally-2-top-2.stl
release/case/sally-2-top.stl
release/case/sally-parts.3mf
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

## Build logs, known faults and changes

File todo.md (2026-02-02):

# to be implemented:
- Silscreen for 27C128 Eprom, not correct (must jump to +5v)

- SIO connection needs a signal shaping switching transistor (inverting) oder two (non-invertng) per line (SIOOUT, CMD, RDY)

- Tests for disk geometry:
 	- does the drive spin at 360 RPM (Yes -> HD, 500 Kbit MFM) (No -> it's a 300 RPM drive)
 	- test for HD (at 300 RPM) (more than 18 sectors/track, 36 for the HDI)
 	- test for DD (250 Kbit MFM 256 bytes/sector)
 	- test for MD (250 Kbit MFM 128 bytes/sector)
 	- test for SD (125 Kbit FM 128 bytes/sector)
 	- After each successful test (on track 0 side 0), the number of tracks is then determined (on side 0) (possibly check for 35 track drive)
 	- is track 40 (which is the 41st track) readable with these settings (No: 40 track drive, Yes: possibly 77 track drive)
 	- is track 77 (which is the 78th track) readable with these settings (No: 77 track drive, Yes: 80 track drive)
 	- After the last successful track test, it must be checked whether this track is also readable on side 1 (No: single sided, Yes: double sided)
 	- Now it's possible that no disk or an unformatted disk is inserted (a problem I didn't have with the HDI, since the disk-change signal is required and used there).
 	- For this case, perhaps a PERCOM block with zeros should be created (or 40 TR, SSSD). The user will simply need to know what the drive is capable of when formatting.

- HD switching:
	If the format command is preceded by a PERCOM block with more than 18 sectors of 256 bytes per sector, the FDC must be switched to HD mode.

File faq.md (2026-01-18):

# known issues / quirks:

- Connection to the SIO-bus needs to be revised as some A8 won't communicate properly. Erhard has looked into it and a fix is on its way...

- If a drive is not working properly or a disk media is not in order, a disk format will show ERROR-173 bad sector at format. Clean your drive or use better media.

- Best boot from Sally or first read a sector from one of the drives (e.g. via show Directory) if you booted from another device.
  Otherwise you won't be able to get or set a percom block

- If you want to format HD disks (500khz), make sure the one to be formatted has been formatted in another HD format before (e.g. via a USB PC drive).
  Sally's HD format will be 77Trks/26Sec/256Bytes. This is a workaround as Sally would normally only allow 3600Rpm type floppys to be used with HD.
  8" and 5 1/4" PC/AT drives normally spin at 360rpm. So I implemented a read IDAM in HD, if it succeeds the drive will be considered 360rpm even though it only spins at 300rpm like normal 3 1/2" PC/AT drives do.

- Always configure Percom-Block using "P" and "O" when using another disk geometry. Also consider to write DOS file anew, MyDos will rember last settings then. 
  This is especially important if drive A (boot drive) should use another format.

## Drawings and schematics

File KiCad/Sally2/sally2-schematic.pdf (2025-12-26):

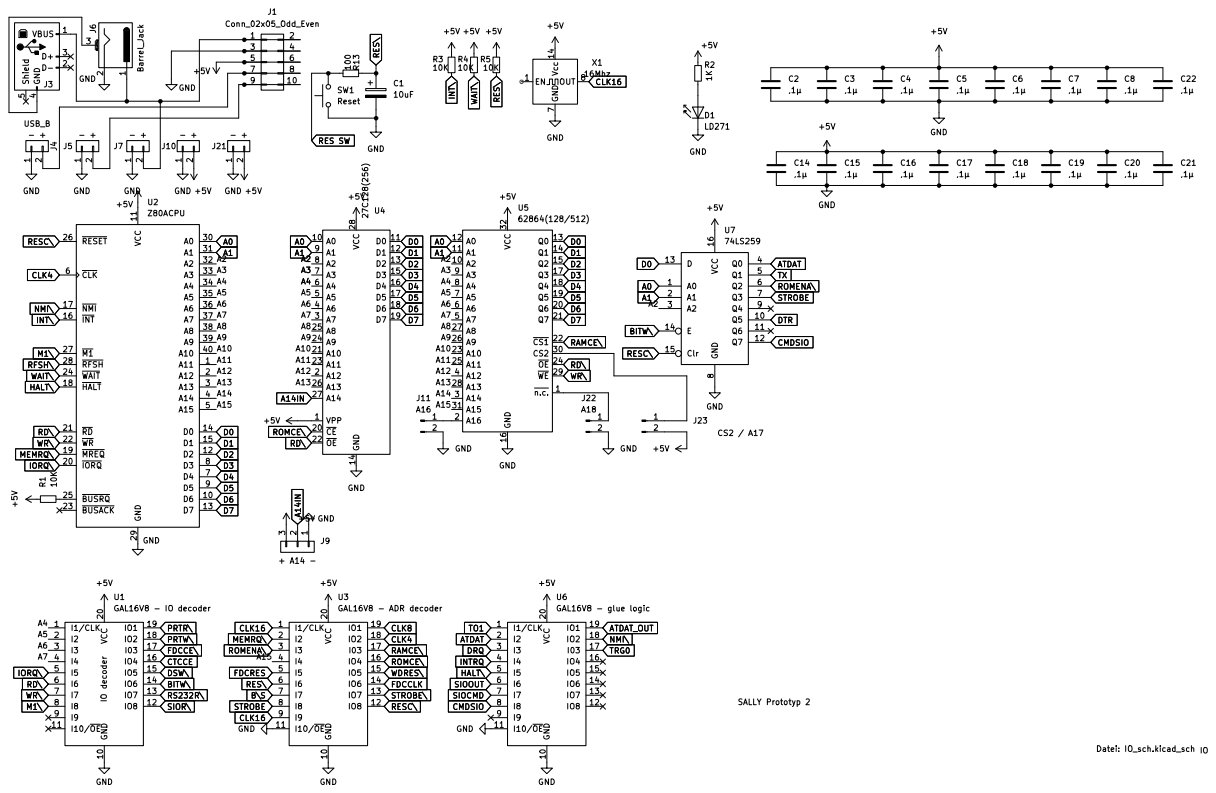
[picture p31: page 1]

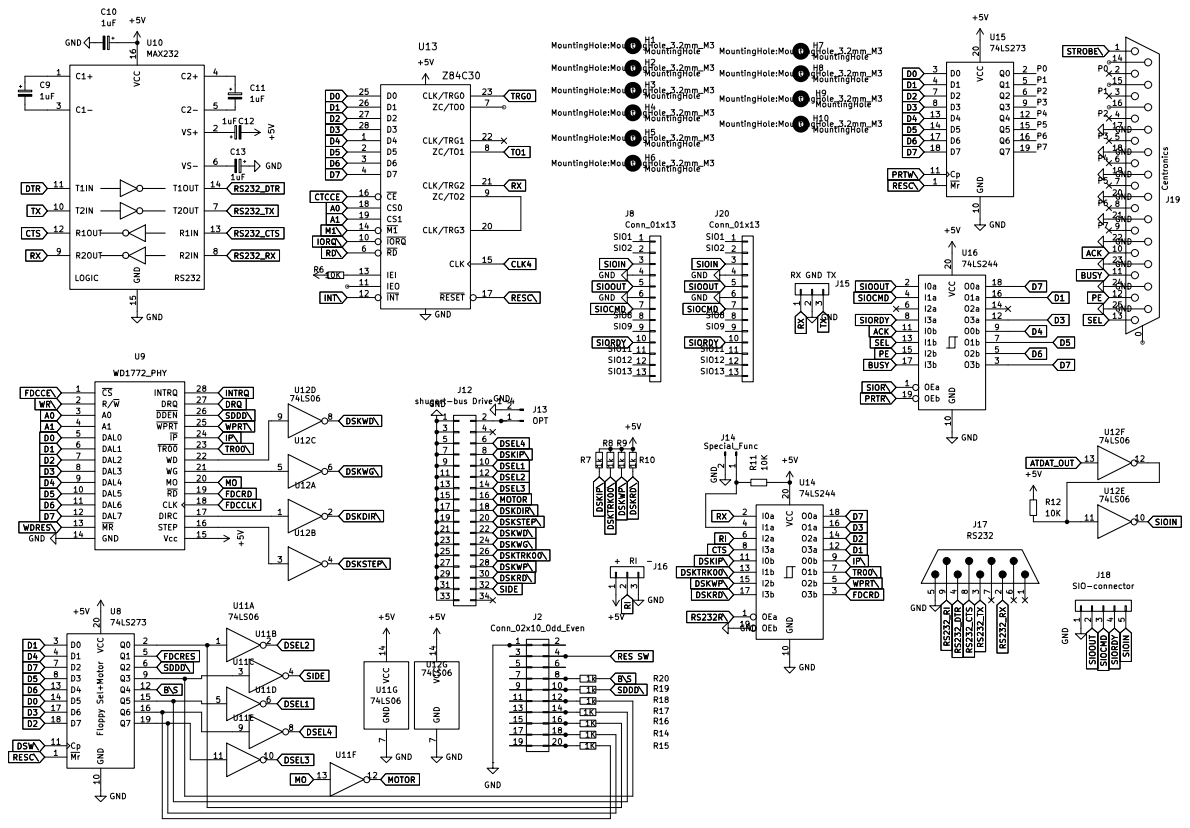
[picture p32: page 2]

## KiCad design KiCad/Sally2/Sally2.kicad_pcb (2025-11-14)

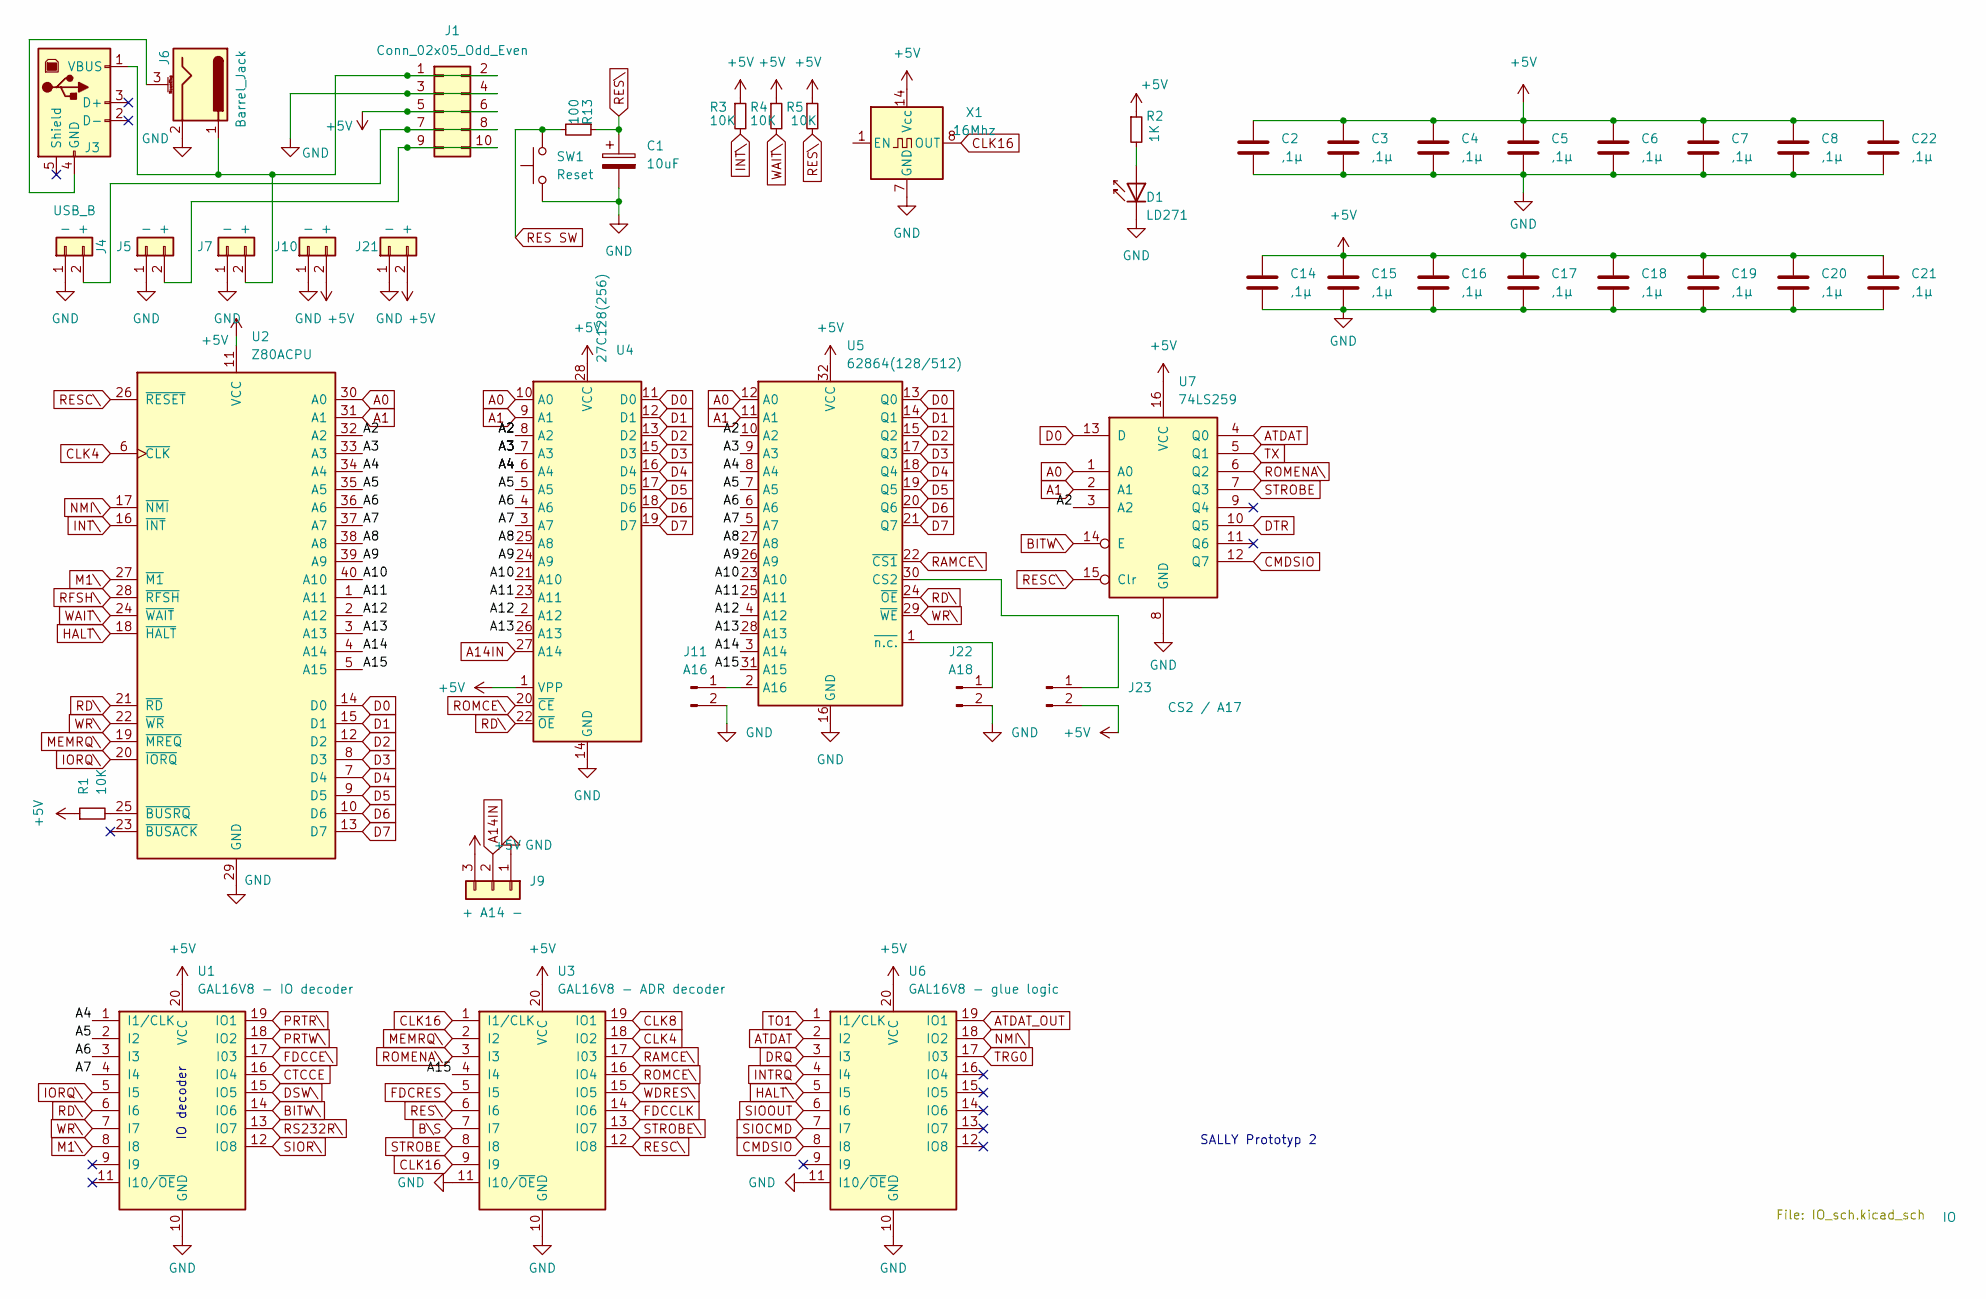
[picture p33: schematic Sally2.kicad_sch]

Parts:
C1: 10uF; CP_Radial_D5.0mm_P2.50mm
C2, C3, C4, C5, C6, C7, C8, C14, C15, C16, C17, C18, C19, C20, C21, C22: ,1µ; C_Disc_D5.0mm_W2.5mm_P5.00mm
D1: LD271; LED_D5.0mm_IRGrey
J1: Conn_02x05_Odd_Even; PinHeader_2x05_P2.54mm_Horizontal
J3: USB_B; USB_B_Lumberg_2411_02_Horizontal
J4, J5, J7, J10, J21: - +; BKL_1x2 72510U_P2.5mm_Vertical
J6: Barrel_Jack; BarrelJack_Horizontal
J9: + A14 -; PinHeader_1x03_P2.54mm_Vertical
J11: A16; PinHeader_1x02_P2.54mm_Vertical
J22: A18; PinHeader_1x02_P2.54mm_Vertical
J23: CS2 / A17; PinHeader_1x02_P2.54mm_Vertical
R1, R3, R4, R5: 10K; R_Axial_DIN0207_L6.3mm_D2.5mm_P10.16mm_Horizontal
R2: 1K; R_Axial_DIN0207_L6.3mm_D2.5mm_P10.16mm_Horizontal
R13: 100; R_Axial_DIN0207_L6.3mm_D2.5mm_P10.16mm_Horizontal
SW1: Reset; C_Rect_L7.5mm_W6.5mm_P5.00mm
U1: GAL16V8 - IO decoder; DIP-20_W7.62mm
U2: Z80ACPU; DIP-40_W15.24mm
U3: GAL16V8 - ADR decoder; DIP-20_W7.62mm
U4: 27C128(256); DIP-28_W15.24mm
U5: 62864(128/512); DIP-32_W15.24mm_Socket
U6: GAL16V8 - glue logic; DIP-20_W7.62mm
U7: 74LS259; DIP-16_W7.62mm
X1: 16Mhz; Oscillator_DIP-14

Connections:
+5V: C2.1, C3.1, C4.1, C5.1, C6.1, C7.1, C8.1, C14.1, C15.1, C16.1, C17.1, C18.1, C19.1, C20.1, C21.1, C22.1, J1.5, J1.6, J9.3, J10.2, J21.2, J23.2, R1.1, R2.1, R3.1, R4.1, R5.1, U1.20 (VCC), U2.11 (VCC), U3.20 (VCC), U4.1 (VPP), U4.28 (VCC), U5.32 (VCC), U6.20 (VCC), U7.16 (VCC), X1.14 (Vcc); also elsewhere on the board
/A2: U2.32 (A2), U4.8 (A2), U5.10 (A2), U7.3 (A2)
/A3: U2.33 (A3), U4.7 (A3), U5.9 (A3)
/A4: U1.1 (I1/CLK), U2.34 (A4), U4.6 (A4), U5.8 (A4)
/A5: U1.2 (I2), U2.35 (A5), U4.5 (A5), U5.7 (A5)
/A6: U1.3 (I3), U2.36 (A6), U4.4 (A6), U5.6 (A6)
/A7: U1.4 (I4), U2.37 (A7), U4.3 (A7), U5.5 (A7)
/A8: U2.38 (A8), U4.25 (A8), U5.27 (A8)
/A9: U2.39 (A9), U4.24 (A9), U5.26 (A9)
/A10: U2.40 (A10), U4.21 (A10), U5.23 (A10)
/A11: U2.1 (A11), U4.23 (A11), U5.25 (A11)
/A12: U2.2 (A12), U4.2 (A12), U5.4 (A12)
/A13: U2.3 (A13), U4.26 (A13), U5.28 (A13)
/A14: U2.4 (A14), U5.3 (A14)
/A15: U2.5 (A15), U3.4 (I4), U5.31 (A15)
A0: U2.30 (A0), U4.10 (A0), U5.12 (A0), U7.1 (A0); also elsewhere on the board
A1: U2.31 (A1), U4.9 (A1), U5.11 (A1), U7.2 (A1); also elsewhere on the board
A14IN: J9.2, U4.27 (A14)
ATDAT: U6.2 (I2), U7.4 (Q0)
ATDAT_OUT: U6.19 (IO1); also elsewhere on the board
BITW\: U1.14 (IO6), U7.14 (E)
B\S: U3.7 (I7); also elsewhere on the board
CLK4: U2.6 (~CLK), U3.18 (IO2); also elsewhere on the board
CLK8: U3.19 (IO1)
CLK16: U3.1 (I1/CLK), U3.9 (I9), X1.8 (OUT)
CMDSIO: U6.8 (I8), U7.12 (Q7)
CTCCE: U1.16 (IO4); also elsewhere on the board
D0: U2.14 (D0), U4.11 (D0), U5.13 (Q0), U7.13 (D); also elsewhere on the board
D1: U2.15 (D1), U4.12 (D1), U5.14 (Q1); also elsewhere on the board
D2: U2.12 (D2), U4.13 (D2), U5.15 (Q2); also elsewhere on the board
D3: U2.8 (D3), U4.15 (D3), U5.17 (Q3); also elsewhere on the board
D4: U2.7 (D4), U4.16 (D4), U5.18 (Q4); also elsewhere on the board
D5: U2.9 (D5), U4.17 (D5), U5.19 (Q5); also elsewhere on the board
D6: U2.10 (D6), U4.18 (D6), U5.20 (Q6); also elsewhere on the board
D7: U2.13 (D7), U4.19 (D7), U5.21 (Q7); also elsewhere on the board
DRQ: U6.3 (I3); also elsewhere on the board
DSW\: U1.15 (IO5); also elsewhere on the board
DTR: U7.10 (Q5); also elsewhere on the board
FDCCE\: U1.17 (I03); also elsewhere on the board
FDCCLK: U3.14 (IO6); also elsewhere on the board
FDCRES: U3.5 (I5); also elsewhere on the board
GND: C1.2, C2.2, C3.2, C4.2, C5.2, C6.2, C7.2, C8.2, C14.2, C15.2, C16.2, C17.2, C18.2, C19.2, C20.2, C21.2, C22.2, D1.1 (K), J1.3, J1.4, J4.1, J5.1, J6.2, J7.1, J9.1, J10.1, J11.2, J21.1, J22.2, SW1.1, U1.10 (GND), U2.29 (GND), U3.10 (GND), U3.11 (I10/~OE), U4.14 (GND), U5.16 (GND), U6.10 (GND), U6.11 (I10/~OE), U7.8 (GND), X1.7 (GND); also elsewhere on the board
HALT\: U2.18 (~HALT), U6.5 (I5)
INTRQ: U6.4 (I4); also elsewhere on the board
INT\: R3.2, U2.16 (~INT); also elsewhere on the board
IORQ\: U1.5 (I5), U2.20 (~IORQ); also elsewhere on the board
M1\: U1.8 (I8), U2.27 (~M1); also elsewhere on the board
MEMRQ\: U2.19 (~MREQ), U3.2 (I2)
NMI\: U2.17 (~NMI), U6.18 (IO2)
unnamed: D1.2 (A), R2.2
unnamed: J1.1, J1.2, J3.1 (VBUS), J6.1, J7.2
unnamed: J1.7, J1.8, J4.2
unnamed: J1.9, J1.10, J5.2
unnamed: J3.4 (GND), J6.3 (MountPin)
unnamed: J11.1, U5.2 (A16)
unnamed: J22.1, U5.1 (~n.c.)
unnamed: J23.1, U5.30 (CS2)
unnamed: R1.2, U2.25 (~BUSRQ)
PRTR\: U1.19 (IO1); also elsewhere on the board
PRTW\: U1.18 (IO2); also elsewhere on the board
RAMCE\: U3.17 (I03), U5.22 (~CS1)
RD\: U1.6 (I6), U2.21 (~RD), U4.22 (~OE), U5.24 (~OE); also elsewhere on the board
RES SW: R13.2, SW1.2; also elsewhere on the board
RESC\: U2.26 (~RESET), U3.12 (IO8), U7.15 (Clr); also elsewhere on the board
RES\: C1.1, R5.2, R13.1, U3.6 (I6)
RFSH\: U2.28 (~RFSH)
ROMCE\: U3.16 (IO4), U4.20 (~CE)
ROMENA\: U3.3 (I3), U7.6 (Q2)
RS232R\: U1.13 (IO7); also elsewhere on the board
SIOCMD: U6.7 (I7); also elsewhere on the board
SIOOUT: U6.6 (I6); also elsewhere on the board
SIOR\: U1.12 (IO8); also elsewhere on the board
STROBE: U3.8 (I8), U7.7 (Q3)
STROBE\: U3.13 (IO7); also elsewhere on the board
TO1: U6.1 (I1/CLK); also elsewhere on the board
TRG0: U6.17 (I03); also elsewhere on the board
TX: U7.5 (Q1); also elsewhere on the board
WAIT\: R4.2, U2.24 (~WAIT)
WDRES\: U3.15 (IO5); also elsewhere on the board
WR\: U1.7 (I7), U2.22 (~WR), U5.29 (~WE); also elsewhere on the board

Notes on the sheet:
SALLY Prototyp 2
IO decoder

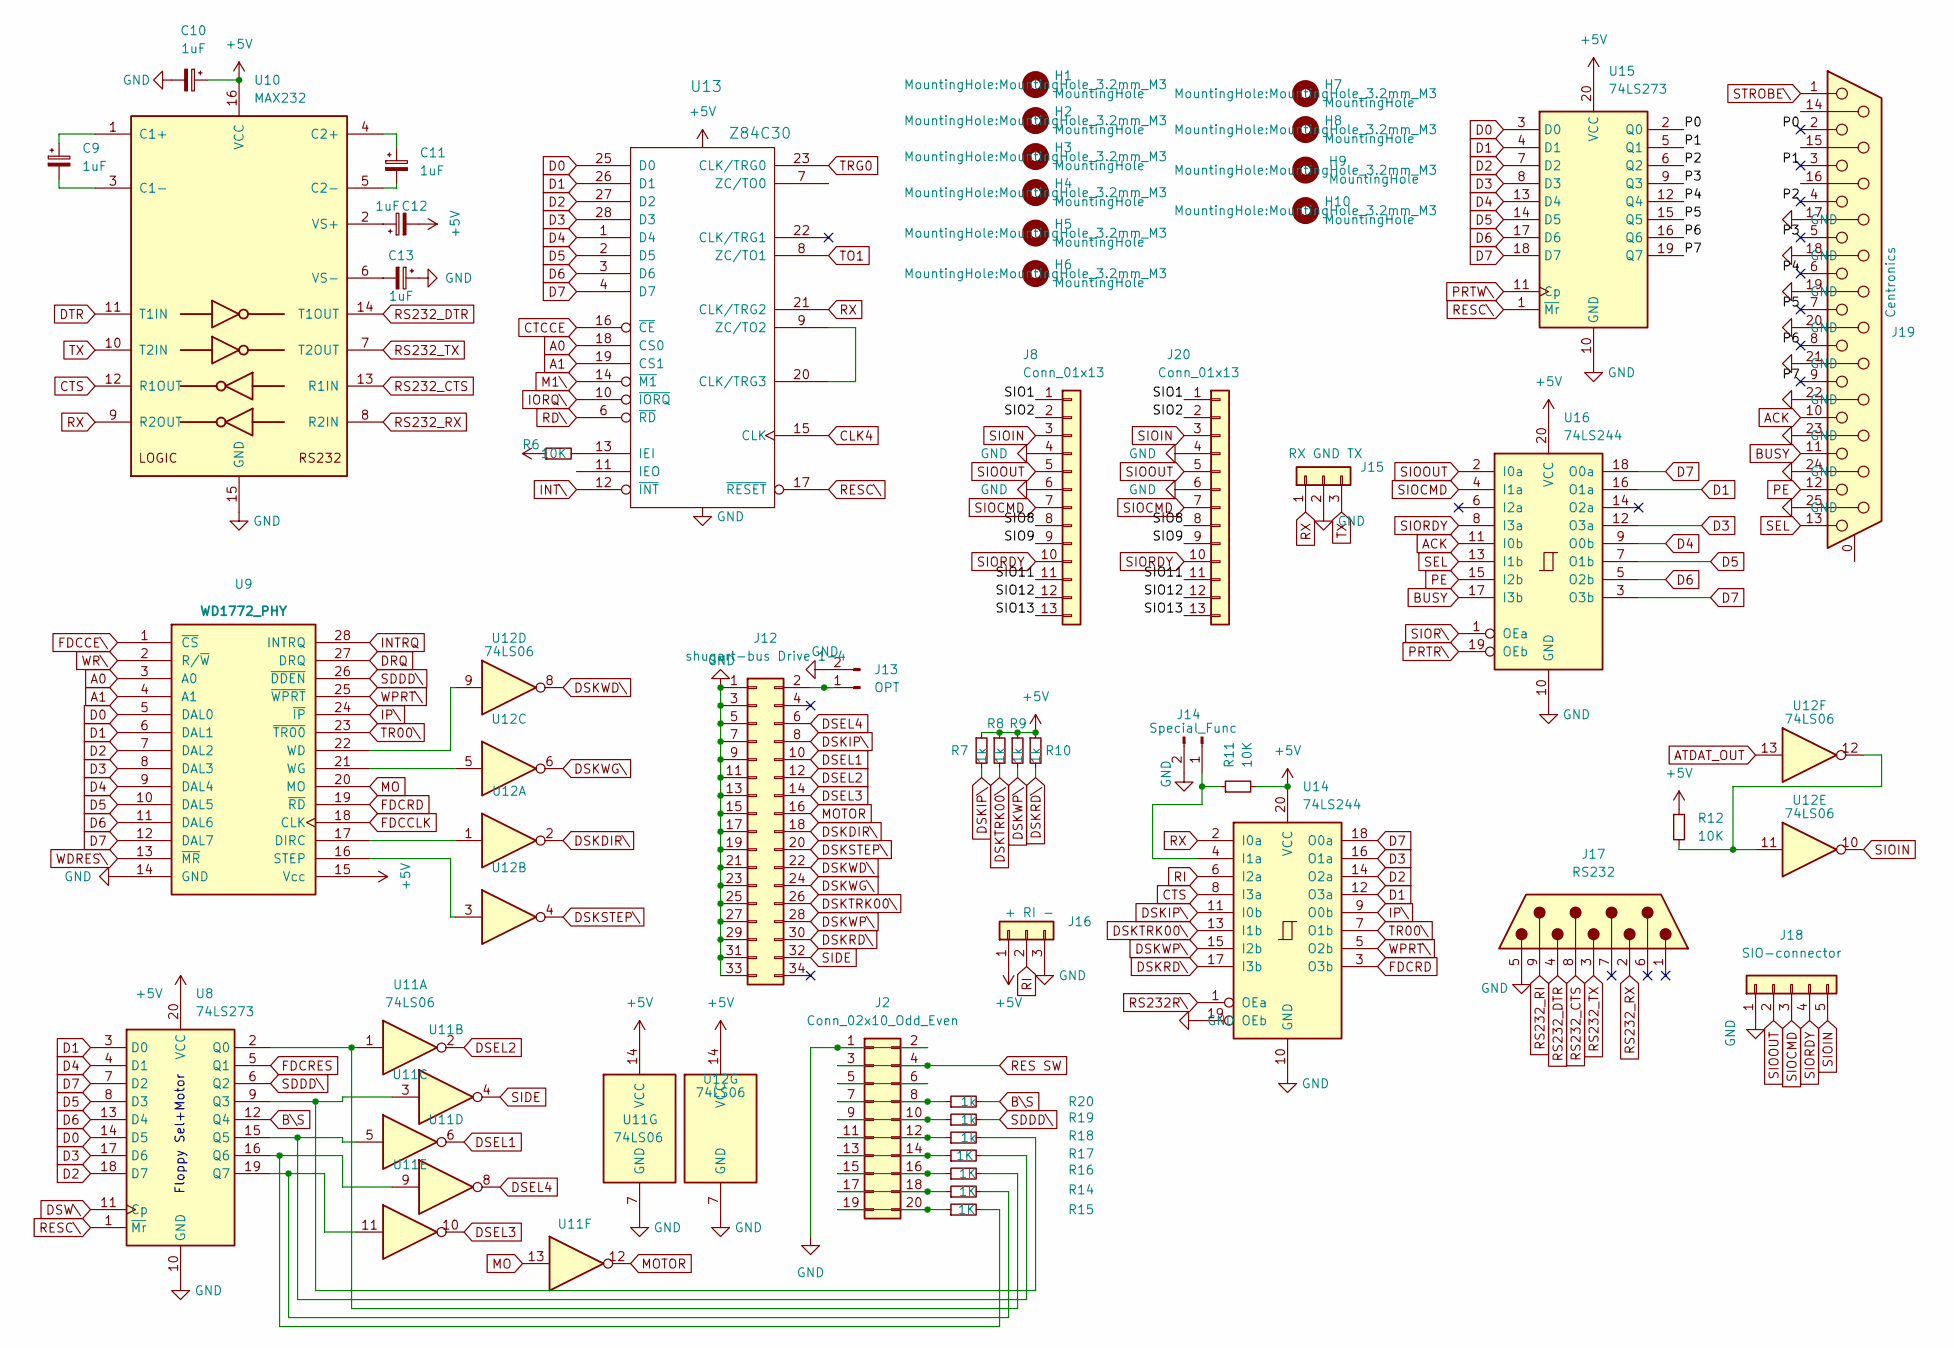
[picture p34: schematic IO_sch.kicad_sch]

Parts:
C9, C10, C11, C12, C13: 1uF; CP_Radial_D5.0mm_P2.50mm
H1, H2, H3, H4, H5, H6, H7, H8, H9, H10: MountingHole; MountingHole_3.2mm_M3
J2: Conn_02x10_Odd_Even; PinHeader_2x10_P2.54mm_Horizontal
J8, J20: Conn_01x13; SIO_JACK
J12: shugart-bus Drive 1-4; IDC-Header_2x17_P2.54mm_Vertical
J13: OPT; PinHeader_1x02_P2.54mm_Vertical
J14: Special_Func; PinHeader_1x02_P2.54mm_Vertical
J15: RX GND TX; PinHeader_1x03_P2.54mm_Vertical
J16: + RI -; PinHeader_1x03_P2.54mm_Vertical
J17: RS232; DSUB-9_Male_Horizontal_P2.77x2.84mm_EdgePinOffset9.90mm_Hou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
J18: SIO-connector; PinHeader_1x05_P2.54mm_Vertical
J19: Centronics; DSUB-25_Female_Horizontal_P2.77x2.84mm_EdgePinOffset7.70mm_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
R6, R11, R12: 10K; R_Axial_DIN0207_L6.3mm_D2.5mm_P10.16mm_Horizontal
R7, R8, R9, R10, R18, R19, R20: 1k; R_Axial_DIN0207_L6.3mm_D2.5mm_P10.16mm_Horizontal
R14, R15, R16, R17: 1K; R_Axial_DIN0207_L6.3mm_D2.5mm_P10.16mm_Horizontal
U8, U15: 74LS273; DIP-20_W7.62mm
U9: WD1772_PHY; DIP-28_W15.24mm_LongPads
U10: MAX232; DIP-16_W7.62mm
U11, U12: 74LS06; DIP-14_W7.62mm_Socket
U13: Z84C30; DIP-28_W15.24mm
U14, U16: 74LS244; DIP-20_W7.62mm

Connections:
+5V: C10.1, C12.2, J16.1, R6.1, R7.1, R8.1, R9.1, R10.1, R11.2, R12.1, U8.20 (VCC), U9.15 (Vcc), U10.16 (VCC), U11.14 (VCC), U12.14 (VCC), U13.24 (VCC), U14.20 (VCC), U15.20 (VCC), U16.20 (VCC); also elsewhere on the board
/IO/P0: J19.2, U15.2 (Q0)
/IO/P1: J19.3, U15.5 (Q1)
/IO/P2: J19.4, U15.6 (Q2)
/IO/P3: J19.5, U15.9 (Q3)
/IO/P4: J19.6, U15.12 (Q4)
/IO/P5: J19.7, U15.15 (Q5)
/IO/P6: J19.8, U15.16 (Q6)
/IO/P7: J19.9, U15.19 (Q7)
/IO/SIO1: J8.1, J20.1
/IO/SIO2: J8.2, J20.2
/IO/SIO8: J8.8, J20.8
/IO/SIO9: J8.9, J20.9
/IO/SIO11: J8.11, J20.11
/IO/SIO12: J8.12, J20.12
/IO/SIO13: J8.13, J20.13
A0: U9.3 (A0), U13.18 (CS0); also elsewhere on the board
A1: U9.4 (A1), U13.19 (CS1); also elsewhere on the board
ACK: J19.10, U16.11 (I0b)
ATDAT_OUT: U12.13; also elsewhere on the board
BUSY: J19.11, U16.17 (I3b)
B\S: R20.2, U8.12 (Q4); also elsewhere on the board
CLK4: U13.15 (CLK); also elsewhere on the board
CTCCE: U13.16 (~CE); also elsewhere on the board
CTS: U10.12 (R1OUT), U14.8 (I3a)
D0: U8.14 (D5), U9.5 (DAL0), U13.25 (D0), U15.3 (D0); also elsewhere on the board
D1: U8.3 (D0), U9.6 (DAL1), U13.26 (D1), U14.12 (O3a), U15.4 (D1), U16.16 (O1a); also elsewhere on the board
D2: U8.18 (D7), U9.7 (DAL2), U13.27 (D2), U14.14 (O2a), U15.7 (D2); also elsewhere on the board
D3: U8.17 (D6), U9.8 (DAL3), U13.28 (D3), U14.16 (O1a), U15.8 (D3), U16.12 (O3a); also elsewhere on the board
D4: U8.4 (D1), U9.9 (DAL4), U13.1 (D4), U15.13 (D4), U16.9 (O0b); also elsewhere on the board
D5: U8.8 (D3), U9.10 (DAL5), U13.2 (D5), U15.14 (D5), U16.7 (O1b); also elsewhere on the board
D6: U8.13 (D4), U9.11 (DAL6), U13.3 (D6), U15.17 (D6), U16.5 (O2b); also elsewhere on the board
D7: U8.7 (D2), U9.12 (DAL7), U13.4 (D7), U14.18 (O0a), U15.18 (D7), U16.3 (O3b), U16.18 (O0a); also elsewhere on the board
DRQ: U9.27 (DRQ); also elsewhere on the board
DSEL1: J12.10, U11.6
DSEL2: J12.12, U11.2
DSEL3: J12.14, U11.10
DSEL4: J12.6, U11.8
DSKDIR\: J12.18, U12.2
DSKIP\: J12.8, R7.2, U14.11 (I0b)
DSKRD\: J12.30, R10.2, U14.17 (I3b)
DSKSTEP\: J12.20, U12.4
DSKTRK00\: J12.26, R8.2, U14.13 (I1b)
DSKWD\: J12.22, U12.8
DSKWG\: J12.24, U12.6
DSKWP\: J12.28, R9.2, U14.15 (I2b)
DSW\: U8.11 (Cp); also elsewhere on the board
DTR: U10.11 (T1IN); also elsewhere on the board
FDCCE\: U9.1 (~CS); also elsewhere on the board
FDCCLK: U9.18 (CLK); also elsewhere on the board
FDCRD: U9.19 (~RD), U14.3 (O3b)
FDCRES: U8.5 (Q1); also elsewhere on the board
GND: C10.2, C13.1, J2.1, J2.2, J8.4, J8.6, J12.1, J12.3, J12.5, J12.7, J12.9, J12.11, J12.13, J12.15, J12.17, J12.19, J12.21, J12.23, J12.25, J12.27, J12.29, J12.31, J12.33, J13.2, J14.2, J15.2, J16.3, J17.5, J18.1, J19.17, J19.18, J19.19, J19.20, J19.21, J19.22, J19.23, J19.24, J19.25, J20.4, J20.6, U8.10 (GND), U9.14 (GND), U10.15 (GND), U11.7 (GND), U12.7 (GND), U13.5 (GND), U14.10 (GND), U14.19 (OEb), U15.10 (GND), U16.10 (GND); also elsewhere on the board
INTRQ: U9.28 (INTRQ); also elsewhere on the board
INT\: U13.12 (~INT); also elsewhere on the board
IORQ\: U13.10 (~IORQ); also elsewhere on the board
IP\: U9.24 (~IP), U14.9 (O0b)
M1\: U13.14 (~M1); also elsewhere on the board
MO: U9.20 (MO), U11.13
MOTOR: J12.16, U11.12
unnamed: J2.5, J2.6
unnamed: J2.7, J2.8, R20.1
unnamed: J2.9, J2.10, R19.1
unnamed: J2.11, J2.12, R18.1
unnamed: J2.13, J2.14, R17.1
unnamed: J2.15, J2.16, R16.1
unnamed: J2.17, J2.18, R14.1
unnamed: J2.19, J2.20, R15.1
unnamed: J12.2, J13.1
unnamed: J14.1, R11.1, U14.4 (I1a)
unnamed: R12.2, U12.11, U12.12
unnamed: R16.2, U8.2 (Q0), U11.1
unnamed: R18.2, U8.9 (Q3), U11.3
unnamed: R17.2, U8.15 (Q5), U11.5
unnamed: R15.2, U8.16 (Q6), U11.9
unnamed: R14.2, U8.19 (Q7), U11.11
unnamed: U9.17 (DIRC), U12.1
unnamed: U9.16 (STEP), U12.3
unnamed: U9.22 (WD), U12.9
unnamed: U9.21 (WG), U12.5
unnamed: C9.1, U10.1 (C1+)
unnamed: C9.2, U10.3 (C1-)
unnamed: C11.1, U10.4 (C2+)
unnamed: C11.2, U10.5 (C2-)
unnamed: C12.1, U10.2 (VS+)
unnamed: C13.2, U10.6 (VS-)
unnamed: U13.9 (ZC/TO2), U13.20 (CLK/TRG3)
unnamed: R6.2, U13.13 (IEI)
PE: J19.12, U16.15 (I2b)
PRTR\: U16.19 (OEb); also elsewhere on the board
PRTW\: U15.11 (Cp); also elsewhere on the board
RD\: U13.6 (~RD); also elsewhere on the board
RES SW: J2.3, J2.4; also elsewhere on the board
RESC\: U8.1 (~Mr), U13.17 (~RESET), U15.1 (~Mr); also elsewhere on the board
RI: J16.2, U14.6 (I2a)
RS232R\: U14.1 (OEa); also elsewhere on the board
RS232_CTS: J17.8, U10.13 (R1IN)
RS232_DTR: J17.4, U10.14 (T1OUT)
RS232_RI: J17.9
RS232_RX: J17.2, U10.8 (R2IN)
RS232_TX: J17.3, U10.7 (T2OUT)
RX: J15.1, U10.9 (R2OUT), U13.21 (CLK/TRG2), U14.2 (I0a)
SDDD\: R19.2, U8.6 (Q2), U9.26 (~DDEN)
SEL: J19.13, U16.13 (I1b)
SIDE: J12.32, U11.4
SIOCMD: J8.7, J18.3, J20.7, U16.4 (I1a); also elsewhere on the board
SIOIN: J8.3, J18.5, J20.3, U12.10
SIOOUT: J8.5, J18.2, J20.5, U16.2 (I0a); also elsewhere on the board
SIORDY: J8.10, J18.4, J20.10, U16.8 (I3a)
SIOR\: U16.1 (OEa); also elsewhere on the board
STROBE\: J19.1; also elsewhere on the board
TO1: U13.8 (ZC/TO1); also elsewhere on the board
TR00\: U9.23 (~TR00), U14.7 (O1b)
TRG0: U13.23 (CLK/TRG0); also elsewhere on the board
TX: J15.3, U10.10 (T2IN); also elsewhere on the board
WDRES\: U9.13 (~MR); also elsewhere on the board
WPRT\: U9.25 (~WPRT), U14.5 (O2b)
WR\: U9.2 (R/~W); also elsewhere on the board

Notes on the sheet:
Floppy Sel+Motor

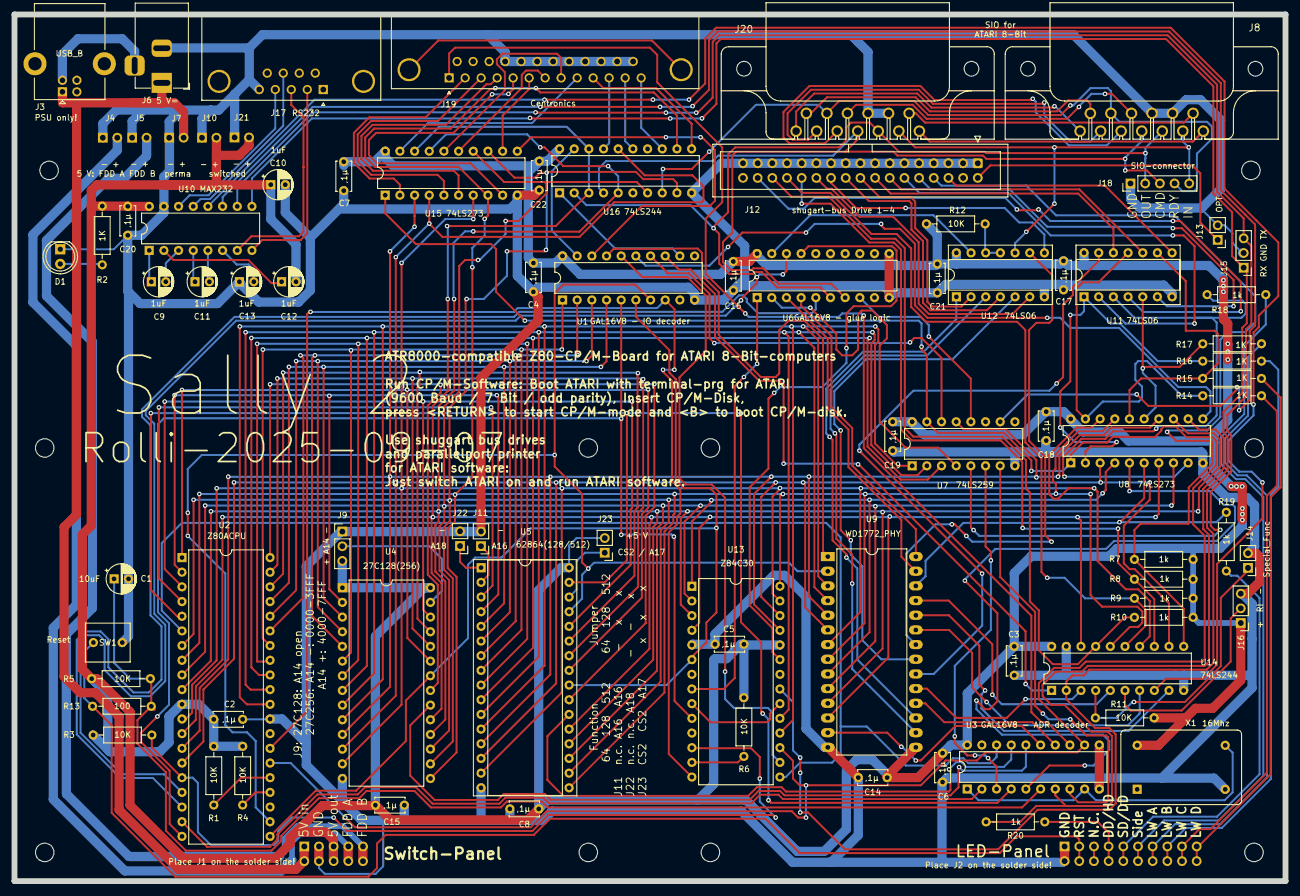
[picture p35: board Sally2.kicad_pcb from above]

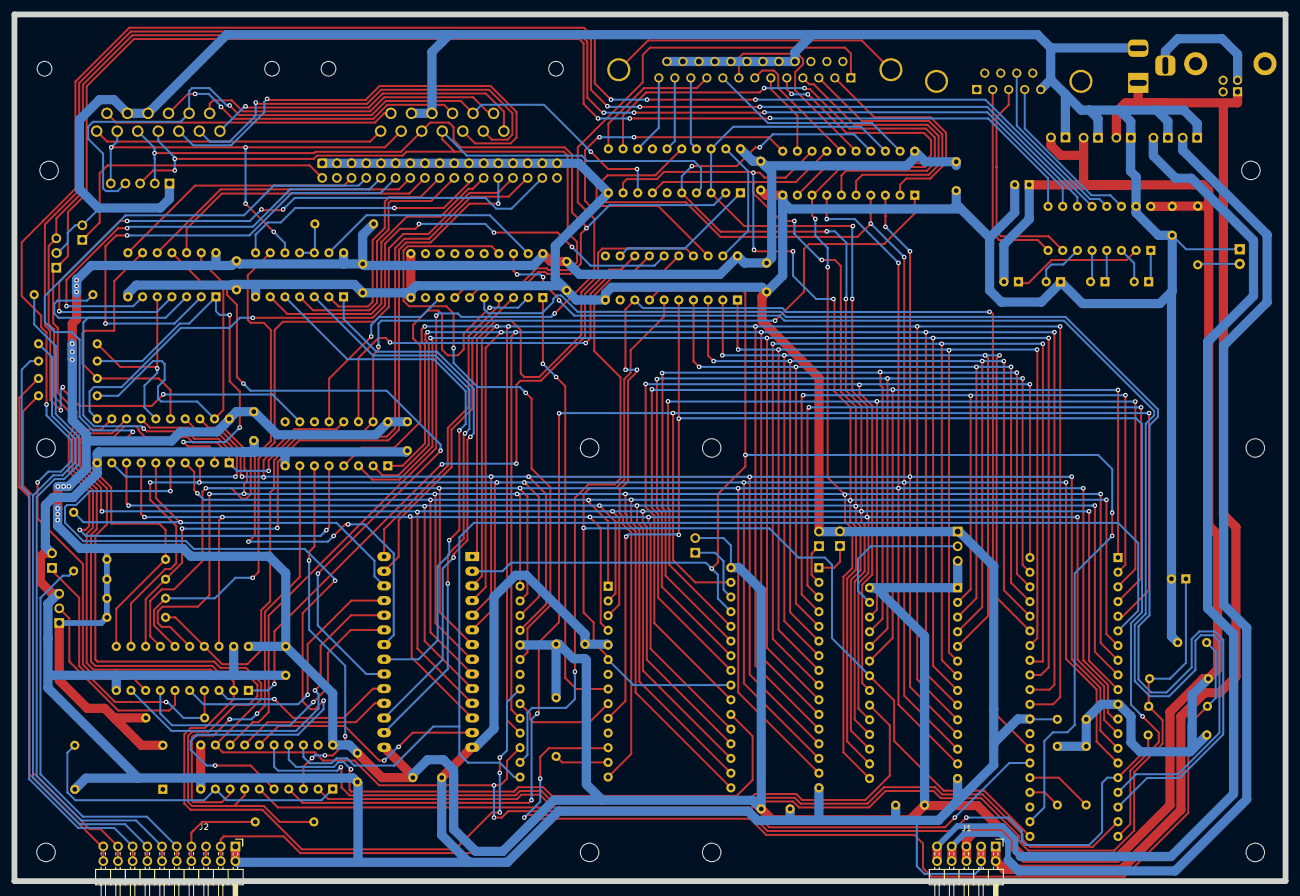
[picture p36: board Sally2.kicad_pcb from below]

Board: 2 copper layers, 220.0 x 150.0 mm, 94 parts (2 on the bottom side), 154 nets.

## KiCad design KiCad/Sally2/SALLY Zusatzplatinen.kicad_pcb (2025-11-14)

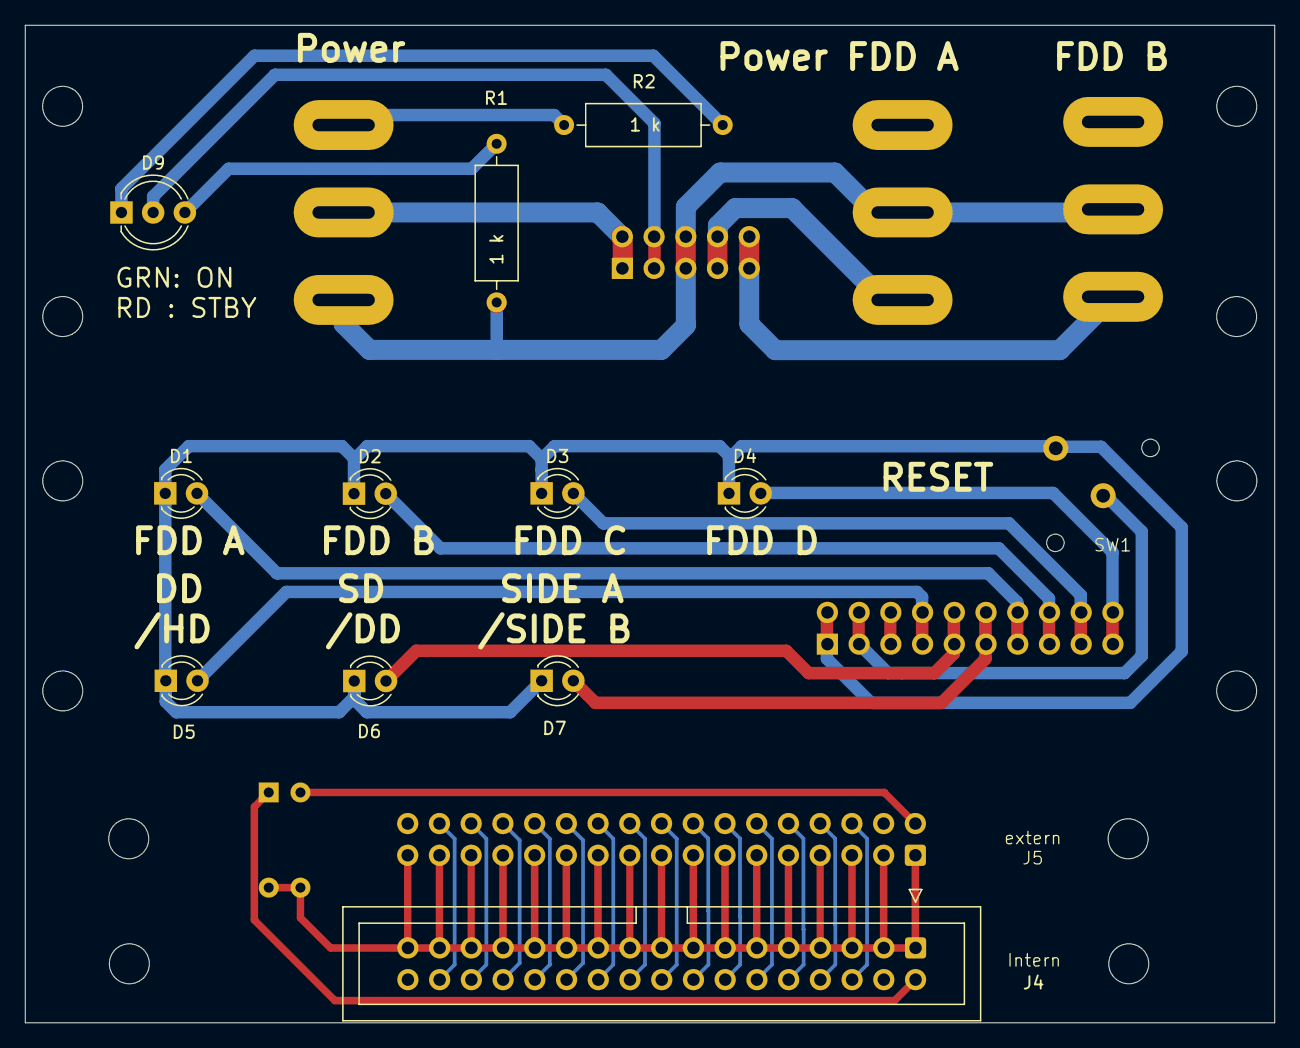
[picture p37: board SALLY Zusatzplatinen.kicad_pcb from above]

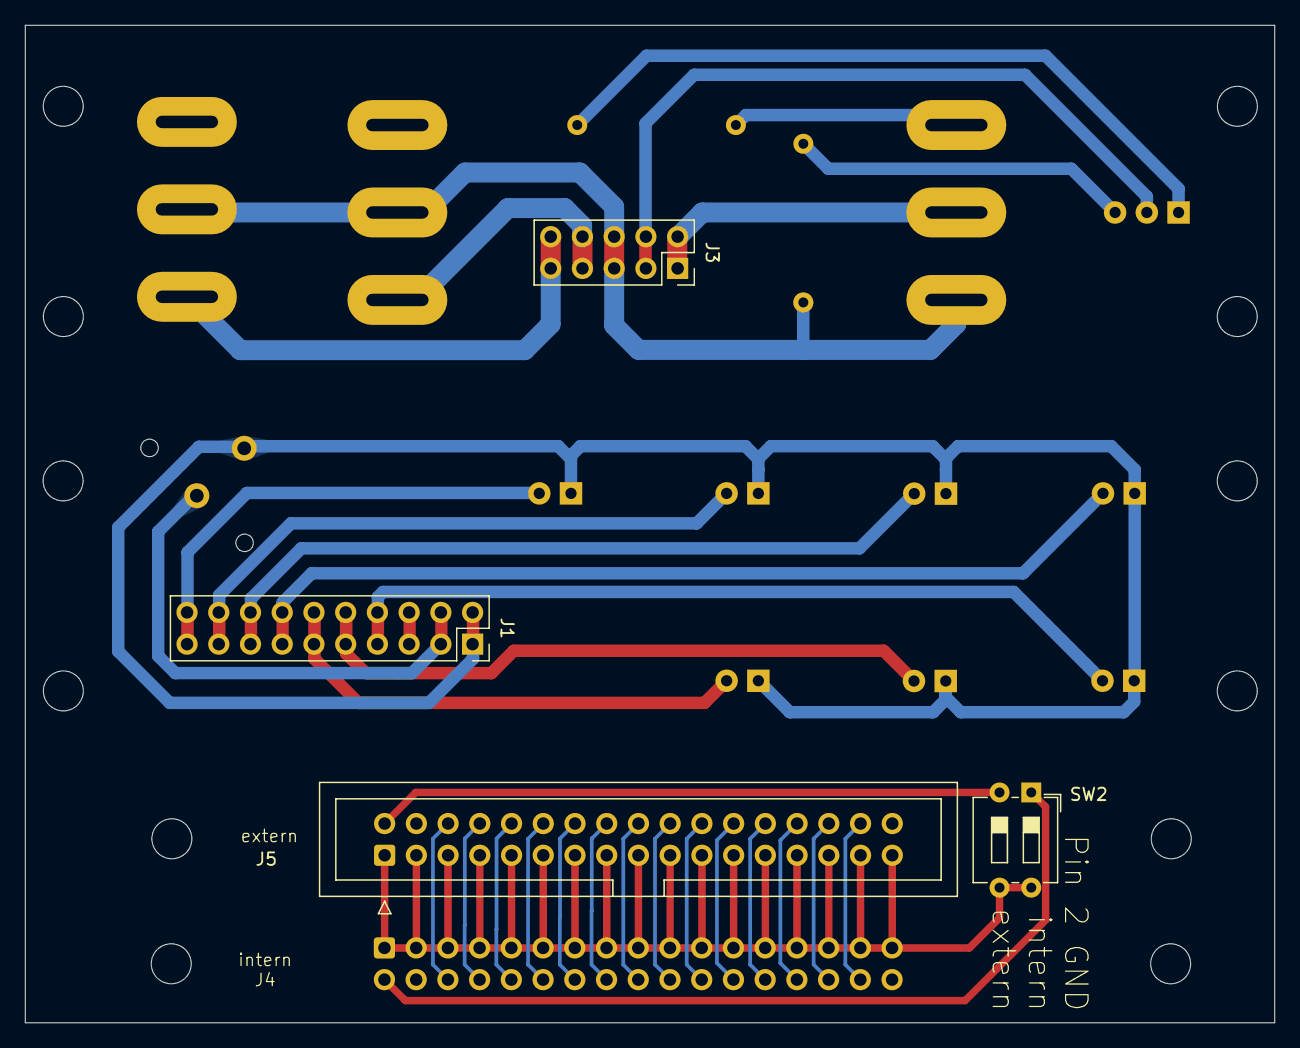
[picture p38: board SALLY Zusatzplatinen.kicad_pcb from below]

Board: 2 copper layers, 100.0 x 79.9 mm, 31 parts (4 on the bottom side), 34 nets.

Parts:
D1: LW A; LED_D3.0mm
D2: LW B; LED_D3.0mm
D3: LW C; LED_D3.0mm
D4: LW D; LED_D3.0mm
D5: BS; LED_D3.0mm
D6: DD; LED_D3.0mm
D7: Side; LED_D3.0mm
D9: LED_Dual_AKA; LED_D5.0mm-3
FDD_A1: SW2; MARQUARDT KIPP 1813.1102
FDD_B1: SW3; MARQUARDT KIPP 1813.1102
H1, H2, H3, H4, H5, H6, H7, H8, H9, H10, H11, H12: MountingHole; MountingHole_3.2mm_M3
J1: Conn_02x10_Odd_Even; PinSocket_2x10_P2.54mm_Vertical
J3: Conn_02x05_Odd_Even; PinSocket_2x05_P2.54mm_Vertical
J4: Mainboard; IDC-Header_2x17_P2.54mm_Vertical
J5: FDD extern; IDC-Header_2x17_P2.54mm_Vertical
Power1: SW1; MARQUARDT KIPP 1813.1102
R1, R2: 1 k; R_Axial_DIN0309_L9.0mm_D3.2mm_P12.70mm_Horizontal
SW1: SW_Push; MTG
SW2: SW_DIP_x02; SW_DIP_SPSTx02_Slide_6.7x6.64mm_W7.62mm_P2.54mm_LowProfile

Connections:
unnamed: D1.2 (A), J1.13, J1.14
unnamed: D1.1 (K), D2.1 (K), D3.1 (K), D4.1 (K), D5.1 (K), D6.1 (K), D7.1 (K), J1.1, J1.2, SW1.1
unnamed: D2.2 (A), J1.15, J1.16
unnamed: D3.2 (A), J1.17, J1.18
unnamed: D4.2 (A), J1.19, J1.20
unnamed: D5.2 (A), J1.7, J1.8
unnamed: D6.2 (A), J1.9, J1.10
unnamed: D7.2 (A), J1.11, J1.12
unnamed: D9.1 (A1), R2.1
unnamed: D9.3 (A2), R1.1
unnamed: D9.2 (K), J3.3, J3.4
unnamed: FDD_A1.3 (A), J3.7, J3.8
unnamed: FDD_A1.2 (B), FDD_B1.2 (B), J3.5, J3.6, Power1.3 (A), R1.2
unnamed: FDD_B1.3 (A), J3.9, J3.10
unnamed: J1.3, J1.4, SW1.2
unnamed: J3.1, J3.2, Power1.2 (B)
unnamed: J4.1, J4.3, J4.5, J4.7, J4.9, J4.11, J4.13, J4.15, J4.17, J4.19, J4.21, J4.23, J4.25, J4.27, J4.29, J4.31, J4.33, J5.1, J5.3, J5.5, J5.7, J5.9, J5.11, J5.13, J5.15, J5.17, J5.19, J5.21, J5.23, J5.25, J5.27, J5.29, J5.31, J5.33, SW2.3, SW2.4
unnamed: J4.2, SW2.1
unnamed: J4.6, J5.6
unnamed: J4.8, J5.8
unnamed: J4.10, J5.10
unnamed: J4.12, J5.12
unnamed: J4.14, J5.14
unnamed: J4.16, J5.16
unnamed: J4.18, J5.18
unnamed: J4.20, J5.20
unnamed: J4.22, J5.22
unnamed: J4.24, J5.24
unnamed: J4.26, J5.26
unnamed: J4.28, J5.28
unnamed: J4.30, J5.30
unnamed: J4.32, J5.32
unnamed: J5.2, SW2.2
unnamed: Power1.1 (C), R2.2

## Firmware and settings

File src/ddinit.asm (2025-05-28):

LATCH		equ	30h
CMDREG		equ	40h
STSREG		equ	40h
TRKREG		equ	41h
SECREG		equ	42h
DATREG		equ	43h

READSEC		equ	88h
FORCEINT	equ	0d0h
RESTORE		equ	01h
STEPIN		equ	04bh

NULL		equ	000h
CR			equ	00dh
LF			equ	00ah


     		ORG	00100h
;
; Disassembly of the file "C:\github\Sally-1\ATR8000-CPM\ddinit.com"
; 
; CPU Type: Z80
; 
; Created with dZ80 2.0
; 
; on Saturday, 24 of August 2024 at 11:42 AM
; 
     		ld	sp,0c69h
     		ld	bc,0018h			;c = 24
l0106:		push	bc
     		call	printstr
		db	CR, LF,NULL
     		pop	bc
l010e:		ex	(sp),hl
     		ex	(sp),hl
     		ex	(sp),hl
     		ex	(sp),hl
     		djnz	l010e				;waste some time		
     		dec	c
     		jr	nz,l0106			;24 x newline
		
     		call	printstr
		db	".... ATR8000 Disk Formatter  2.1 ....",CR, LF,LF,NULL
		
      		ld	a,(0218h)			;first time called?
     		or	a
     		jp	nz,0219h
     		ld	a,01h
     		ld	(0218h),a
		
     		call	printstr
		db	"This program erases all recorded data",CR, LF
		db	"in the process of formatting. Please",CR, LF
		db	"remove any valuable diskettes before",CR, LF
		db	"proceeding ... ", NULL
		
l01d5:		ld	hl,0000h
l01d8:		push	hl
     		call	const
     		pop	hl
l01dd:		jr	nz,l01e6		; (+07h)
     		dec	hl
     		ld	a,h
     		or	l
     		jr	nz,l01d8		; (-0ch)
     		jr	l01e9		; (+03h)
		
l01e6:		call	getupper
l01e9:		push	af
     		call	printstr
		db	CR, LF, NULL
     		pop	af
l01f1:		cp	03h
     		jr	nz,l0219		; (+24h)
     		call	printstr
		db	CR, LF, LF, "returning to CP/M ... ", CR, LF, LF, NULL
     		jp	0000h
		
l0218:		nop
l0219:		call	printstr
		db	CR, LF
		db	"--- Disk Format Menu ---", CR, LF, LF
		db	"   density   sector size",CR, LF
		db	"   -------   -----------",CR, LF
		db	"1) single     128 bytes",CR, LF
		db	"2) double     256 bytes",CR, LF
		db	"3) double     512 bytes",CR, LF
		db	"4) double    1024 bytes", CR, LF, LF
		db	"enter number of format (1 thru 4) ... ", NULL

l02f9:		call	06c7h
     		cp	31h
     		jr	c,l02f9
     		cp	35h
     		jr	nc,l02f9
     		sub	31h
     		ld	(067bh),a			;sector size 
		
		call	printstr
		db	CR, LF, "enter drive name (A,B,C or D) ....... ", NULL
l0335:		call	06c7h
     		cp	41h
     		jr	c,l0335
     		cp	45h
     		jr	nc,l0335
     		sub	41h
     		ld	(0682h),a			;drive no
     		xor	a
     		ld	(0680h),a			;bits 7: single / double = 1
l0349:		call	printstr
		db	CR, LF, "single or double sided (S or D) ..... ", NULL
		
l0375:		call	06c7h
     		cp	53h
     		jr	z,l0385
     		cp	44h
     		jr	nz,l0375
     		ld	hl,0680h
     		set	7,(hl)
l0385:		call	printstr
		db	CR, LF, NULL
		ld      a,(0682h)
		add     a,41h
		ld      (03bch),a
		
		
		call	printstr
		db	CR, LF, "press <Y> when ready to format disk A",CR, LF
		db	"or <CTL-C> to exit to CP/M ... ", NULL
		
l03df:		call	070bh
     		call	getupper
     		cp	03h
     		jp	z,01f5h
     		cp	59h		;'Y'
     		jr	z,l03f4		; (+06h)
     		call	conout
     		jp	0100h
		
l03f4:		call	printstr
		db	CR, LF, LF, NULL
		
     		ld	ix,0681h			;select drive 
l03ff:		call	0f00fh
     		ld	a,(0689h)
     		bit	7,a
     		jr	z,l044e		; (+45h)
l0409:		call	printstr
		db	"*** DRIVE NOT READY ***",CR, LF
		db	"(drive door open?  disk in wrong?)",CR, LF, 7, NULL
l044b:		jp	038bh

l044e:		bit	6,a
     		jr	z,l048d		; (+3bh)
     		call	printstr
		db	"*** WRITE PROTECTED ***",CR, LF
		db	"(check write protect tab)",CR, LF, NULL
     		jp	038bh
		
l048d:		call	printstr
		db	CR, LF, NULL
		
     		ld	hl,0000h
     		ld	(0636h),hl
     		ld	(0638h),hl
     		ld	a,(067bh)			;sector size lo
     		or	a
     		ld	a,(0687h)
     		jr	z,l04a9		; (+04h)
     		res	7,a
l04a7:		jr	l04ab		; (+02h)
l04a9:		set	7,a				;if sec size lo = 0, set bit 7 in 687h
l04ab:		ld	(0687h),a
     		ld	hl,063bh
l04b1:		bit	6,a
     		jr	z,l04b8		; (+03h)
     		ld	hl,0657h
l04b8:		ld	de,0673h
     		ld	bc,0007h
     		ld	a,(067bh)
     		and	03h
     		jr	z,l04c9		; (+04h)
l04c5:		add	hl,bc
     		dec	a
     		jr	nz,l04c5		; (-04h)
l04c9:		ldir

     		ld	a,(0677h)
     		ld	h,a
     		ld	a,(0675h)
     		ld	l,a
l04d3:		call	09a1h
     		ld	hl,(0001h)
     		ld	bc,0018h
     		add	hl,bc
     		ld	a,(0682h)
     		ld	c,a
     		ld	b,00h
     		ld	de,0ffffh
     		call	05c2h
     		ld	bc,0023h
l04ec:		add	hl,bc
l04ed:		ld	a,(hl)
     		or	a
     		jr	z,l04f4		 
     		ld	(0676h),a
l04f4:		ld	a,(0080h)
     		cp	03h
     		jr	nz,l0532		
     		ld	hl,(0081h)
     		ld	bc,2f20h
     		or	a
     		sbc	hl,bc
     		jr	nz,l0532		
     		ld	a,(0083h)
     		cp	30h
     		jr	nz,l051a		
     		ld	hl,09d6h
     		ld	a,(0677h)
l0513:		dec	(hl)
     		inc	hl
     		dec	a
     		jr	nz,l0513		 
     		jr	l0532		 
l051a:		ld	a,50h			;80 tracks
     		ld	(0676h),a
     		xor	a
     		ld	(067fh),a
     		ld	a,(0083h)
     		cp	44h
     		jr	nz,l0532
     		ld	a,28h			;40 tracks
     		ld	(067fh),a
     		ld	(0676h),a
l0532:		di
     		ld	a,03h
     		out	(83h),a
     		ei
     		call	l0777
     		in	a,(TRKREG)
     		out	(DATREG),a
     		ld	a,10h			;FDC seek
     		out	(CMDREG),a
     		xor	a
     		out	(LATCH),a
     		call	printstr
		db	CR, LF, LF, NULL
     		ld	hl,0676h
     		ld	a,(067ah)
     		inc	a
     		cp	(hl)
     		jr	nc,l0569		; (+12h)
     		call	printstr
		db	"aborted ... ", NULL
l0567:		jr	l0576		; (+0dh)

l0569:		call	printstr
		db	"done ... ", NULL
		
l0576:		ld	hl,(0636h)
     		ld	a,h
     		or	l
     		jr	nz,l059a		; (+1dh)
     		call	printstr
		db	"no bad sectors detected", NULL
     		jr	l05b9		; (+1fh)
l059a:		ld	hl,(0636h)
     		call	072bh
l05a0:		call	printstr
		db	" bad sectors detected", NULL
		
l05b9:		call	printstr
		db	CR, LF, NULL
     		jp	038bh
		
     		jp	(hl)
		
prttrack:     	call	printstr
		db	CR, "TRACK ", NULL
		
l05ce:		ld	a,(067fh)
     		or	a
     		ld	a,(067ah)
     		jr	z,l05d8		; (+01h)
     		add	a,a
l05d8:		ld	h,00h
     		ld	l,a
     		call	072bh
     		ld	a,(0680h)
     		bit	7,a
     		jr	z,l05fa		; (+15h)
     		call	printstr
		db	"  SIDE ", NULL
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

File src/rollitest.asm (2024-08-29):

;--------------------------------------------------
; out\ ports
;--------------------------------------------------
; $2x 	Printer DATA
; $3x	Floppy Control	D7 = S/D\, D6 = HD\/S, D5 = Side, D4 = FDCRES, D3 = DSEL4, D2 = DSEL3, D1 = DSEL1, D0 = DSEL0
; $4x	FDC 1797
; $5x	U52 74LS259
; 	$50	ATARI Out data
; 	$51	RS232 TX
; 	$52	ROM switch
; 	$53	printer strobe
; 	$54	reset index-pulse
; 	$55	RS232 DTR
; 	$56	set index pulse
; 	$57	0=CMD,  1=SIO
; $8x	CTC
;--------------------------------------------------
; in\ ports
;--------------------------------------------------
; $2x	Printer Control
; $4x	FDC 1797
; $5x	RS232	D7=RX,  D3=1,  D2=?,  D1=FlowControl
; $70	SIO	D7=RX,  D3=RDY/+5V, D1=CMD
;--------------------------------------------------
;
;	... DATA STRUCTURE FOR DISK I/O CONTROL BLOCK ...
;
DSKOP		equ	0		;DISK OPERATION CODE
DSKDRV		equ	1		;DRIVE# (WITH SIDE# IN BIT 7)
DSKTRK		equ	2		;TRACK#
DSKSEC		equ	3		;SECTOR#
DSKPTR		equ	4		;READ/WRITE POINTER
DSKAUX		equ	6		;AUXILLIARY PARAMETERS (2 BYTES)
DSKSTS		equ	8		;OPERATION COMPLETION STATUS
		
	
TRKREG		equ	FDCTRK
DATREG		equ	FDCDAT
CMDREG		equ	FDCCMD
SECREG		equ	FDCSEC
STSREG		equ	FDCSTAT

INDXSET		equ	SETIDX
INDXCLR		equ	RESIDX

CTC0		equ	TC0
CTC1		equ	TC1
CTC2		equ	TC2
CTC3		equ	TC3
CTCVEC		equ	TC0INTVEC

LATCH		equ	DISKCTRL

;
RIDCMD		equ	11000000B	;READ ID COMMAND
RDCMD		equ	10001000B	;READ COMMAND
WRTCMD		equ	10101000B	;WRITE COMMAND
FINCMD		equ	11010000B	;FORCE INTERRUPT COMMAND
;SKCMD		equ	00011000B	;SEEK COMMAND
SKCMD		equ	00010000B	;SEEK COMMAND
RSTCMD		equ	00000000B	;RESTORE COMMAND
STEPOUT		equ	01100000B	;STEP OUT COMMAND
STEPIN		equ	01000000B	;STEP IN COMMAND
;HLOAD		equ	00001000B	;HEAD LOAD BIT FOR TYPE 1 COMMANDS
HLOAD		equ	00000000B	;HEAD LOAD BIT FOR TYPE 1 COMMANDS

		include "SALLY-CONST.asm"

		org	00000h
		
		jp	start
		
		dw	0, 0, 0, 0, 0, 0, 0, 0, 0, 0, 0, 0, 0, 0, 0, 0
		dw	0, 0, 0, 0, 0, 0, 0, 0, 0, 0, 0, 0, 0, 0, 0, 0
		dw	0, 0, 0, 0, 0, 0, 0, 0, 0, 0, 0, 0, 0, 0, 0, 0
		dw	0, 0, 0, 0, 0, 0, 0, 0, 0, 0, 0, 0, 0, 0, 0, 0
		dw	0, 0, 0, 0, 0, 0, 0, 0, 0, 0, 0, 0, 0, 0, 0, 0
		dw	0, 0, 0, 0, 0, 0, 0, 0, 0, 0, 0, 0, 0, 0, 0, 0
		dw	0, 0, 0, 0, 0, 0, 0, 0, 0, 0, 0, 0, 0, 0, 0, 0
		dw	0, 0, 0, 0, 0, 0, 0, 0, 0, 0, 0, 0, 0, 0
		db	0	
		
		
;--------------------------------------------------
; conin T/C 0 (here counter) interrupt for start-bit
;--------------------------------------------------		
coninInt:	push	af
     		ld	a, 87h
     		out	(TC0), a			;set T/C 0 to 9600 Baud timer 
baud9600:     	ld	a, CONBAUD;01ah			;26 * 16 = 416; 4Mhz/416 = 9600 baud
     		out	(TC0), a
     		ld	a, coninIntB & 255		;set T/C 0 interrupt to next routine
     		ld	(TC0INTVEC), a
     		ld	a, 7fh
coninInt1:	ld	(inbyte + 1), a
     		pop	af
     		ei
     		reti

coninIntB:    	push	af
     		in	a, (SIOIN)			;read RS232-	RX
     		rla
inbyte:    	ld	a, 00h				;<- set by previous routine to 7fh
     		rra
     		jr	c, coninInt1			;loop 7 times
		
coninIntPtr:    ld	(KEYBUF), a			;store result in ff00
     		ld	a, coninIntC & 255		;timer 0 interrupt vector = 0ff2c
		ld	(TC0INTVEC), a
     		pop	af
     		ei
     		reti

coninIntC:     	push	af
     		ld	a, 0c7h				;timer 0 counter
     		out	(TC0), a
     		ld	a, 01h
     		out	(TC0), a
     		ld	a, (coninIntPtr + 1)
     		inc	a
     		and	0fh
     		ld	(coninIntPtr + 1), a		;increment buffer (16 bytes)
     		ld	a, coninInt & 255		;reset T/C 0 interrupt to start-bit routine
     		ld	(TC0INTVEC), a
     		pop	af
     		ei
     		reti


;--------------------------------------------------
; conout T/C 1 interrupt for start-bit
;--------------------------------------------------		
conoutIntA:     push	af
     		xor	a
     		out	(SIOOUT), a
     		ld	a, conoutIntB & 255
     		ld	(TC1INTVEC), a
     		pop	af
     		ei
     		reti

conoutIntB:	push	af
		ld	a, 00h
     		out	(SIOOUT), a
     		rra
     		ld	(conoutIntC + 2), a
     		ld	a, conoutIntC & 255
     		ld	(TC1INTVEC), a
     		pop	af
     		ei
     		reti

conoutIntC:	push	af
     		ld	a, 00h
     		out	(SIOOUT), a
     		rra
     		ld	(conoutIntD + 2), a
     		ld	a, conoutIntD & 255
     		ld	(TC1INTVEC), a
     		pop	af
     		ei
     		reti

conoutIntD:	push	af
     		ld	a, 00h
     		out	(SIOOUT), a
     		rra
     		ld	(conoutIntE + 2), a
     		ld	a, conoutIntE & 255
     		ld	(TC1INTVEC), a
     		pop	af
     		ei
     		reti

conoutIntE:	push	af
     		ld	a, 00h
     		out	(SIOOUT), a
     		rra
     		ld	(conoutIntF + 2), a
     		ld	a, conoutIntF & 255
     		ld	(TC1INTVEC), a
     		pop	af
     		ei
     		reti

conoutIntF:	push	af
     		ld	a, 00h
     		out	(SIOOUT), a
     		rra
     		ld	(conoutIntG + 2), a
     		ld	a, conoutIntG & 255
     		ld	(TC1INTVEC), a
     		pop	af
     		ei
     		reti

conoutIntG:	push	af
     		ld	a, 00h
     		out	(SIOOUT), a
     		rra
     		ld	(conoutIntH + 2), a
     		ld	a, conoutIntH & 255
     		ld	(TC1INTVEC), a
     		pop	af
     		ei
     		reti

conoutIntH:	push	af
     		ld	a, 00h
     		out	(SIOOUT), a
     		rra
     		ld	(conoutIntI + 2), a
     		ld	a, conoutIntI & 255
     		ld	(TC1INTVEC), a
     		pop	af
     		ei
     		reti

conoutIntI:	push	af
     		ld	a, 00h
     		out	(SIOOUT), a
     		ld	a, conoutIntJ & 255
     		ld	(TC1INTVEC), a
     		pop	af
     		ei
     		reti

conoutIntJ:	push	af
     		ld	a, 01h				;stop bit
     		out	(SIOOUT), a
     		ld	a, resetConout & 255
     		ld	(TC1INTVEC), a
     		pop	af
     		ei
     		reti

resetConout: 	push	af				;disable timer 1 interrupt
     		ld	a, 01h
     		out	(TC1), a
     		ld	a, 0ffh
     		ld	(TC1INTVEC), a
     		pop	af
     		ei
     		reti
		
;--------------------------------------------------
; Code executed after Reset
;--------------------------------------------------
start:		di      				; disable interrupt
		xor     a				; set a to zero
restime:	dec     a				; do 256 times nothing
		jr      nz, restime			; loop 

		
		ld      hl, portval			; init 11 ports with values at 0a3h
		ld      b, 0ah              
portinit:	ld      c, (hl)             
		inc     hl                 
		outi   			 	 
		jr      nz, portinit			; loop

		ld      sp, 0c100h			; stack-pointer

		ld	hl, 00000h			; source
		ld	(VARS + addr), hl
		ld	de, 08000h			; dest
		ld	bc, 02000h
		ldir
		
		ld	hl, code8000
		set	7, h
		jp	(hl)
code8000:	ld	a, 1
		out	(ROMSWITCH), a
		
		ld	hl, 08000h
		ld	de, 00000h
		ld	bc, 02000h
		ldir
		jp	code0000
		
code0000:	ld      a, 0ffh				; load interrupt-vector register
		ld      i, a				; with 0ffh
		im      2				; enable interrupt mode 2 (vectored)
		
			
     		call	init9600			;init 9600 baud send/receive
		
		ld	a, 041h
		out	(DISKCTRL), a
		
		ld	b, 5	
stepinloop:	call	stepin
		djnz	stepinloop
	
stepoutloop:	call	stepout
		in	a, (FDCSTAT)
		bit	2, a
		jr	z, stepoutloop

		call	waitmotor
		ld	a, 040h
		out	(DISKCTRL), a
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

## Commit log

2024-09-18 kill timer
2024-10-20 printer buffer length
2024-12-08 IO groß
    [io_sch.kicad_sch]
2024-12-08 IO_sch raus
    [io_sch.kicad_sch]
2024-12-08 IO_sch rein
    [IO_sch.kicad_sch]
2025-04-12 case 1st try
    [sally-2-back.scad, sally-2-back.stl, sally-2-bottom.scad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]
2025-04-15 Sally-2 case
    [sally-2-back.scad, sally-2-back.stl, sally-2-front.scad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]
2025-04-15 front duo-led
    [sally-2-back.scad, sally-2-back.stl, sally-2-bottom.scad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]
2025-04-20 Sally-2 readme case
2025-05-01 case update
    [IO_sch.kicad_sch, Sally2.kicad_sch, sally-2-bottom.scad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]
2025-05-01 black case
2025-05-08 +pcb pic
2025-05-10 CPM added
    [sally-2-back.scad, sally-2-back.stl, sally-2-top-1.3mf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]
2025-05-26 case front/back
    [sally-2-back.3mf, sally-2-back.scad, sally-2-back.stl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]
2025-07-09 WD1772 compile var and formatting
    [sally-2-front-text.3mf, sally-2-front-text.scad, sally-2-front-text.stl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]
2025-09-01 worked on case
    [sally-2-back-text.3mf, sally-2-back-text.scad, sally-2-back-text.stl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]
2025-09-05 worked on front (case)
    [sally-2-bottom.3mf, sally-2-bottom.scad, sally-2-bottom.stl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]
2025-09-20 DINIT3 reverted
    [sally-2-front-text.3mf]
2025-10-03 Michael Meincke Ed.
    [sally-2-back-text.3mf, sally-2-front-text-logo.3mf, sally-2-front-text-logo.scad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]
2025-10-28 add more stuff to release drawer
    [sally-2-back-text.3mf, sally-2-back-text.stl, sally-2-back.stl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]
2025-11-14 KiCad merges from Marc
    [IO_sch.kicad_sch, SALLY Zusatzplatinen.kicad_pcb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]
2025-11-14 Autoterm load at $1f00 fixed
    [sally-2-top-2.3mf]
2025-11-24 sally tools
    [sally-2-back-text.3mf, sally-2-back-text.stl, sally-2-back.stl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]
2025-12-26 steprate 3ms fixed
    [IO_sch.kicad_sch]
2026-02-17 4 Sec Motor On
2026-03-11 4 sec timer improved
2026-10-15 100ms analyse time and 3mf for case
2026-11-04 Minor bugfixing case top

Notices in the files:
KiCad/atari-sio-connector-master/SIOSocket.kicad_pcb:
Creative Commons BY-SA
